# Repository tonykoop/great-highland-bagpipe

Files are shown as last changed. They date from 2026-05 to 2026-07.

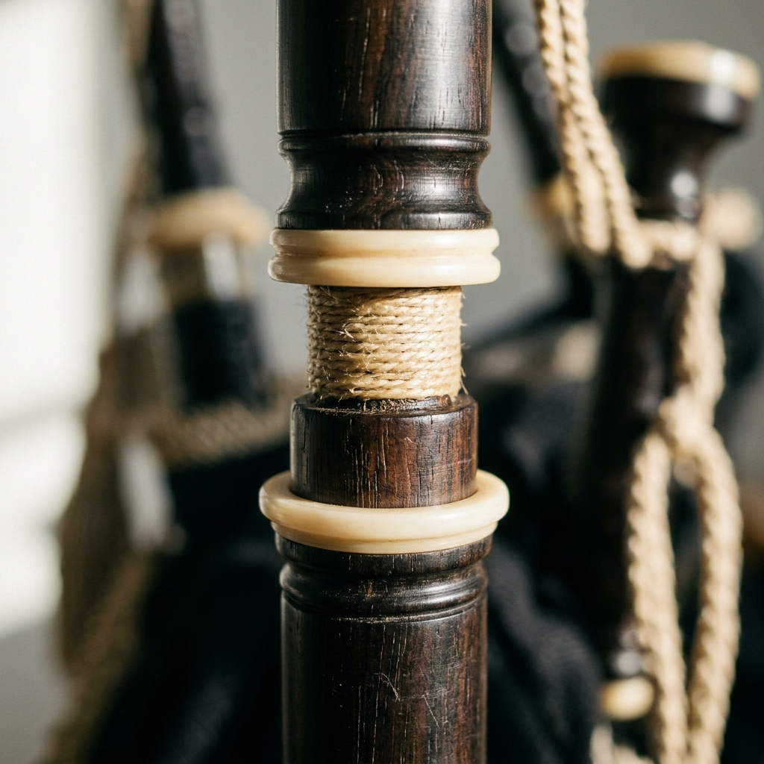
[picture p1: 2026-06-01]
images/macro/hemped-tuning-slide.png

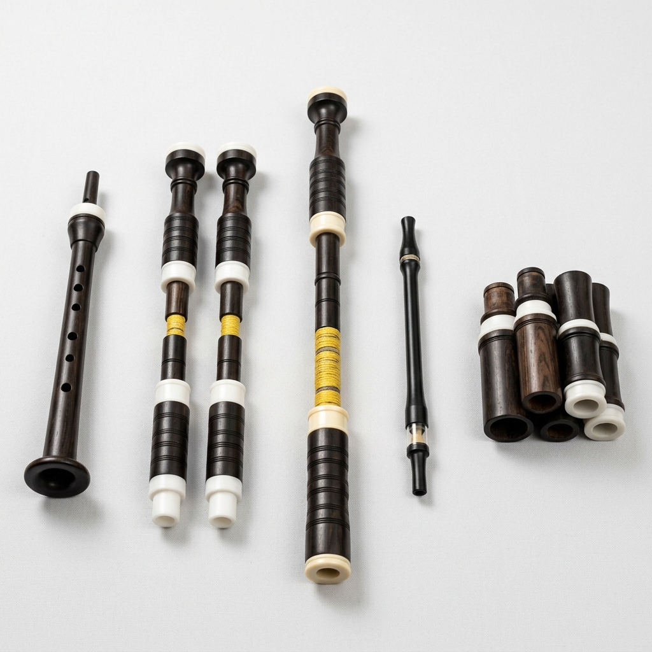
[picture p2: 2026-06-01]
images/family-group.png

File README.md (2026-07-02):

# Great Highland Bagpipe

> A system-of-systems engineering packet for a full Great Highland Bagpipe set:
> chanter, drones, reeds, bag, stocks, blowpipe, pressure regulation, tuning,
> sourcing, maintenance, and validation.

Great Highland Bagpipe system map

## GitHub Repo Metadata

**Description:** Parametric Great Highland Bagpipe build packet covering the
chanter, tenor and bass drones, reeds, bag pressure, stocks, blowpipe, tuning,
maintenance, sourcing, and validation.

**Suggested topics:** `great-highland-bagpipe`, `bagpipe`, `woodwind`,
`reed-instrument`, `parametric-design`, `acoustic-modeling`, `cnc-lathe`,
`woodturning`, `wolfram`, `instrument-making`, `build-packet`

## What This Is

This repository turns the Great Highland Bagpipe workbook into an L2/L3-candidate
packet. It treats the instrument as an interacting set of subsystems rather
than a single pipe: the conical double-reed chanter, two tenor drones, one bass
drone, three drone reeds, one chanter reed, five stocks, blowpipe valve,
reservoir bag, hemped tuning slides, and a maintenance/validation loop.

The design starts from `great-highland-bagpipe-design-table.xlsx`, which uses a
modern GHB Low A of 480 Hz, just-intonation chanter ratios, and first-pass
dimensions for a full chanter and drone set. Formula-derived dimensions are
marked as first-order estimates until confirmed against a physical reed, bore,
and pressure setup.

## Packet Map

- [`design.md`](design.md) - governing acoustic model, subsystem interfaces,
  pressure model, assumptions, and hardware alignment.
- [`bom.csv`](bom.csv) - bill of materials with part categories, operations,
  drawing references, and substitute rules.
- [`sourcing.csv`](sourcing.csv) - supplier/search tracker with current-check
  fields left for purchasing.
- [`cut-list.csv`](cut-list.csv) - rough and finished stock sizes for chanter,
  drones, stocks, blowpipe, mounts, and fixtures.
- [`validation.csv`](validation.csv) - tuning, pressure, leakage, fit, and
  maintenance checks.
- [`reed-pressure-validation.csv`](reed-pressure-validation.csv) - reed source
  roles, onset/cutoff pressure gates, and coupled pressure-response evidence
  rows kept at measurement-required status until real manometer/tuner data
  exists.
- [`assembly-manual.md`](assembly-manual.md) - shop sequence from reeds-first
  testing through final maintenance.
- [`risks.md`](risks.md) - acoustic, structural, ergonomic, supply, and
  fit/finish risk tests.
- [`drawings/`](drawings/) - first-pass dimensioned SVG sheets.
- [`cad/`](cad/) - parametric OpenSCAD master starter.
- [`wolfram/`](wolfram/) - generated Wolfram source package (chanter/drone
  stopped-pipe model); source-only, not executed.
- [`evolution/`](evolution/) - evolution-pipeline Stage 0 intake: master
  manifest, design-intent, and revision register (Gate A not yet run).
- [`site/`](site/) - static build-log site generated from the packet.

## System Architecture

| Subsystem | Function | First Prototype Decision |
| --- | --- | --- |
| Chanter | Conical double-reed melody pipe | Use the workbook's 14.5 in full-chanter length and tune holes from undersize with a commercial reed. |
| Tenor drones | Two stopped cylindrical A3 reference pipes | Build both identically; validate one tenor before copying the second. |
| Bass drone | Stopped cylindrical A2 reference pipe | Build in bottom/middle/top sections with long tuning overlap. |
| Reeds | Oscillating valves and pitch drivers | Buy commercial chanter and drone reeds for prototype stability. |
| Bag | Pressure reservoir | Buy synthetic zipper bag for repeatable airtightness. |
| Stocks and blowpipe | Airtight mechanical interfaces | Turn as separate service parts with hemped or tied-in seals. |
| Maintenance | Keeps the system stable | Add leakage, hemp, moisture, and reed checks to every validation pass. |

## Build Order

1. Buy reeds and bag first, because the acoustic system cannot be validated
   without real pressure and real reed behavior.
2. Turn a practice/prototype chanter in cherry, walnut, Delrin, or ipe before
   committing African blackwood.
3. Validate the chanter bore and note holes using tape and incremental
   enlargement.
4. Build one tenor drone, tune its reed seat and slide behavior, then duplicate
   it.
5. Build the bass drone after tenor tuning and leakage are stable.
6. Turn stocks and blowpipe, tie into the bag, and run full pressure tests.

## Status

**Status:** L2 V5 build-packet candidate

All required V5 baseline files present. All validation gates remain
`Pending` — instrument is not build-ready until reed, bore, and pressure
measurements are completed.

| Area | Status |
| --- | --- |
| V5 readiness | L2 candidate — visual-output-register.csv and cad/mcp-session-log.md present |
| Workbook | Existing `great-highland-bagpipe-design-table.xlsx` inspected and promoted into packet files |
| Acoustic model | First-order conical chanter plus stopped cylindrical drones documented |
| Manufacturing plan | Lathe/CNC workflow and cut list drafted |
| Sourcing | Prototype and final-material sourcing tracker drafted |
| Validation | Tuning, pressure, leakage, fit, maintenance, reed onset/cutoff, and pressure-response checks drafted; all Pending |
| Drawings | First-pass subsystem SVG drawings included (concept_only / derived_preview) |
| CAD | OpenSCAD master starter present; pending_measurement authority |
| Site/deck/print packet | Generated artifacts live at repo root and `site/` |

## License

[CC BY 4.0](LICENSE) - see LICENSE for details.

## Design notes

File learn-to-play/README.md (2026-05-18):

# learn-to-play / Great Highland Bagpipe

Starter songbook for the Great Highland Bagpipe build packet. Generated by the sheet-music skill.

The bagpipe chanter uses a narrow nine-note scale over a constant drone. These arrangements keep the beginner focus on steady pressure, scale familiarity, and clean doublings.

Range: **Low G - High A on the Highland chanter. Written in pipe notation around A mixolydian.**

## Folder map
| Folder | Contents |
|---|---|
| `00-warmup-scales/` | Pipe-scale range walk, birl/doubling drill, drone-pressure long tones |
| `01-easy/` | Three public-domain airs and hymns arranged inside the pipe scale |
| `02-intermediate/` | Two march-style studies with grace-note placeholders |
| `03-original/` | *Heather Drone March* - Heifer Zephyr original |
| `fingering-charts.svg` | Highland chanter fingering chart, Low G to High A |

## Repertoire

### 01-easy
| Tune | Tradition |
|---|---|
| Auld Lang Syne | Scots traditional / Robert Burns (1788) |
| Amazing Grace | John Newton / New Britain tune, public domain |
| Highland Laddie | Trad Scots tune (pre-1800) |

### 02-intermediate
| Tune | Tradition |
|---|---|
| Skye Boat Air | Harold Boulton / Annie MacLeod melody (1884) |
| Pipe Scale March | Original chanter study |

### 03-original
**Heather Drone March** - 32-bar 2/4 march-style original, A mixolydian, quarter=92.

## Notes on notation
ABC files are learner sketches, not full pipe-band settings. Grace-note groups are marked plainly and should be replaced by house-style embellishments during instruction.

## L2 readiness and known gaps
This starter songbook is ready for L2 review as a playable packet draft: ABC melodies, per-tune notes, static fingering summaries, warmups, and a top-level chart are present. Known gaps: generated audio, MusicXML, LilyPond, MIDI, and printable songsheets are skipped until the shared render dependencies are available; fingering charts need builder review against the final hole layout.

## License
Arrangements MIT-licensed by Tony Koop / Heifer Zephyr. Public-domain tune provenance is listed in each `notes.md`. Original studies are MIT-licensed for performance, recording, arrangement, and adaptation.

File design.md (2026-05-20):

# Great Highland Bagpipe Build Packet

## Intent

Build a first-pass engineering packet for a complete Great Highland Bagpipe set
that exposes the system interactions: chanter bore and reed, drones and drone
reeds, bag pressure, stocks, blowpipe valve, tuning slides, sourcing,
maintenance, and validation. The goal is not to claim a finished concert-grade
set from formulas alone; it is to define the measured build loop that gets from
workbook geometry to a playable, serviceable prototype.

## Catalog Metadata

| Field | Value |
| --- | --- |
| Instrument ID | GHB-001 |
| Slug | great-highland-bagpipe |
| Family | reed |
| Pipeline | cnc-lathe |
| Reference workbook | `great-highland-bagpipe-design-table.xlsx` |
| Done-bar family | reed woodwinds, closest local sisters: `chalumeau`, `duduk` |
| Date | 2026-05-08 |

## Design Inputs

| Parameter | Workbook value | Notes |
| --- | ---: | --- |
| Chanter Low A | 480 Hz | Modern GHB pitch, not A440 concert pitch |
| Speed of sound | 13510 in/s | Workbook value, roughly room-temperature air |
| Chanter scale | Mixolydian-like, just intonation | Tuned to drones, not equal temperament |
| Wood reference | African blackwood | Ipe, cocobolo, Delrin, maple, cherry, walnut are prototype alternatives |
| Drone tuning | two A3 tenors, one A2 bass | Tenors one octave below Low A; bass two octaves below |
| Bag pressure | 18-25 inH2O first-pass range | Pressure changes reed pitch and stability |

## Governing Model

The Great Highland Bagpipe is a coupled reed/resonator/reservoir system. The
packet intentionally uses different first-order models for different
subsystems, then validates the coupled result under pressure.

### Chanter

The chanter is a conical bore driven by a double reed. A conical reed pipe
behaves closer to an open-open pipe for pitch than a cylindrical stopped pipe,
but tone holes, reed compliance, and bore taper dominate the final intonation.
The workbook dimensions and measured practice-chanter hole positions are the
starting geometry.

```text
f_chanter ~= c / (2 * L_eff)
L_eff ~= c / (2 * f_target)
c = speed of sound in inches per second
```

Worked example from the workbook:

```text
Low A = 480 Hz
c = 13510 in/s
L_eff = 13510 / (2 * 480) = 14.073 in
Workbook physical full chanter length = 14.5 in
```

The difference between effective and physical length is expected because the
reed seat, conical end behavior, bell flare, and tone-hole network all shift the
effective acoustic length. Final tuning must start with undersize holes and
open them by measurement.

### Drones

The drones are cylindrical single-reed pipes, closed at the reed end and open at
the top. They are first-pass stopped pipes with odd-harmonic emphasis.

```text
f_drone ~= c / (4 * L_eff)
L_eff ~= c / (4 * f_target)
```

Worked examples from the workbook:

```text
Tenor drone A3 = 240 Hz
L_eff = 13510 / (4 * 240) = 14.073 in

Bass drone A2 = 120 Hz
L_eff = 13510 / (4 * 120) = 28.146 in
```

The workbook's physical sections intentionally exceed or subdivide these
effective lengths because tuning chambers, hemped slides, reed seats, and cap
geometry move the acoustic endpoint.

### Bag Pressure And Reeds

The bag is a pressure reservoir, not just a container. The reed only oscillates
inside a stable pressure window. Pressure changes can sharpen or destabilize
the chanter and drones, so every tuning row in `validation.csv` includes
environment and pressure notes.

```text
cents_error = 1200 * log2(measured_hz / target_hz)
pressure_target = 18-25 inH2O for first prototype testing
```

`family-spec.csv` now records the source role for each reed-coupled subsystem.
The chanter is treated as an empirically seeded conical reed pipe for planning
purposes, with final authority coming from purchased double-reed measurements.
The drones are treated as empirically seeded stopped reed pipes, with the
second tenor explicitly blocked from copy status until the first tenor reed,
slide, and pressure response are measured. `reed-pressure-validation.csv`
defines the pressure gates that must be filled before any reed, bore, slide, or
coupled tuning claim can move beyond `measurement_required`.

Do not use the 18-25 inH2O range as measured evidence by itself. It is only the
planned normal-play test window until a manometer log records onset pressure,
normal-play stability, cutoff/choke behavior, reed setting, and cents error for
the selected chanter and drone reeds.

### Empirical Correction Guard

No Native American flute K2 correction is applied here. This packet uses
first-order conical/stopped-pipe estimates plus measured GHB-specific
validation rows. Any future correction must be derived from measured chanter,
drone, reed, and pressure data from this family.

## Chanter Scale Table

| Note | Ratio to Low A | Target Hz at Low A 480 | Model L_eff in | Prototype action |
| --- | ---: | ---: | ---: | --- |
| Low G | 8/9 | 426.67 | 15.832 | Validate as cross/fingering-dependent low note |
| Low A | 1/1 | 480.00 | 14.073 | Establish reed strength and pressure first |
| B | 9/8 | 540.00 | 12.509 | Drill undersize, tape-tune up |
| C written C# | 5/4 | 600.00 | 11.258 | Drill undersize, tune against drones |
| D | 4/3 | 640.00 | 10.555 | Check just fourth against drones |
| E | 3/2 | 720.00 | 9.382 | Watch high hand spacing and hole size |
| F written F# | 5/3 | 800.00 | 8.444 | Small tuning changes are sensitive |
| High G | 7/4 | 840.00 | 8.042 | Treat as cross-fingering/harmonic validation |
| High A | 2/1 | 960.00 | 7.036 | Validate as octave behavior, not a simple hole row |

## Subsystem Interfaces

| Interface | Critical fit | Validation |
| --- | --- | --- |
| Chanter reed to chanter seat | Airtight staple fit, stable blade opening | Reed seats without wobble; Low A speaks at target pressure |
| Chanter stock to bag | Stock tie-in and hemp seal | No bubbles in leak test |
| Drone reed to drone seat | Reed body matches seat diameter | Reed starts, cuts off, and restarts predictably |
| Drone slides | Hemped tenon/socket with tuning travel | Smooth movement, no air loss, no sudden pitch jumps |
| Blowpipe valve | One-way seal | Bag holds pressure when player stops blowing |
| Bag to stocks | Mechanical tie-in | 60-second pressure hold test |

## Hardware Alignment

| Operation | Tooling | Fixture | Notes |
| --- | --- | --- | --- |
| Chanter exterior turning | Lathe roughing/detail tools | Between centers, then chuck/collet | Leave extra length for holding and trimming |
| Chanter conical bore | Step drills plus custom tapered reamer | Headstock-driven deep bore setup | Bore straightness is a high-risk acoustic variable |
| Tone holes | Drill press or mill, undersize bits | V-block indexed to front/back datum | Open by reaming/sanding while measuring pitch |
| Drone cylindrical bores | Long brad-point/twist drills, reamers | Lathe center drilling and steady rest | Build one tenor as process proof |
| Tuning slides | Lathe turning and parting tools | Matched tenon/socket gauges | Hemp clearance must be planned, not guessed |
| Stocks | Lathe boring tools | Batch fixture for repeated stock bodies | Tie-in groove must not cut too deep |
| Mounts/ferrules | Lathe, optional laser engraving | Mandrels for Delrin/ferrule rings | Keep decorative parts removable in prototype |

## Build Strategy

Prototype order is deliberately reeds-first and pressure-first:

1. Buy three chanter reeds and one synthetic drone reed set.
2. Buy a synthetic zipper bag and blowpipe valve before final tuning work.
3. Build a practice/prototype chanter in cherry, walnut, ipe, or Delrin.
4. Validate bore, reed, and hole tuning before building African blackwood.
5. Build one tenor drone, then duplicate it after measured success.
6. Build the bass drone after slide and reed behavior are stable.
7. Tie in stocks, run leakage tests, and maintain a tuning/pressure log.

## Assumptions And Unknowns

| Item | Status | Why it matters |
| --- | --- | --- |
| Chanter bore station table | Derived from workbook and practice measurements | Final intonation needs measured stations, not only a linear cone |
| Reed brand/strength | Unknown until purchased | Reed compliance changes pitch, pressure, and response |
| Bag actual volume | Supplier-dependent | Affects stability and ergonomic squeeze behavior |
| Drone reed seat dimensions | Must match chosen reeds | Synthetic reed body diameters vary |
| Final decorative mount dimensions | Flexible | Do not let ornament drive acoustic or service dimensions |

## Validation Plan

Validation starts with the subsystem, then moves to the coupled system:

1. Bench leak test every stock, reed seat, slide, and bag tie-in.
2. Measure pressure at start, normal play, and cut-off for chanter and drones.
3. Tune drones without the chanter, then add chanter and listen for beating.
4. Record note frequency, cents error, pressure, temperature, humidity, reed,
   and corrective action in `validation.csv`.
5. Repeat after 24 hours to catch hemp compression, bag leakage, and moisture
   effects.

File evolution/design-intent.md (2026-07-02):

# Design Intent — great-highland-bagpipe rev A

- Master CAD: `cad/great-highland-bagpipe-master.scad` (sha256: 7bcdc95fce3c7fae077277482be11eb72df51515757a26632cf0f1e08deeaa63), driven by `great-highland-bagpipe-design-table.xlsx` (sha256: 3ddafd30d57a32bd5da541066588c79f2f1255a5bc5907dc597e76836bcbe0d7)
- Function: Full Great Highland Bagpipe system — conical-bore chanter (open-open, cane double reed) coupled to two tenor + one bass stopped-pipe drones (synthetic/cane reeds), fed by a pressurized bag (18-25 inH2O first-pass range) through a blowpipe one-way valve and turned stocks. Chanter plays a just-intonation Mixolydian-like scale tuned to the drones, not equal temperament (design.md).
- Environment: hand-blown, sustained-pressure system; reed response and drone onset/cutoff are pressure-dependent; wood body (African blackwood preferred, Delrin/ipe/cherry for prototyping) is a coupled reed/resonator/reservoir system, not a simple first-order pipe.
- Target qty: 1 (prototype set — 1 chanter, 2 tenor drones, 1 bass drone). Deadline: TBD. Budget/unit ceiling: TBD.

## Critical dimensions (carry tolerances)

| Feature | Nominal | Tolerance | Why critical | Source |
| --- | --- | --- | --- | --- |
| Chanter Low A | 480 Hz | onset/normal-play/cutoff pressure logged (validation.csv) | pitch reference, not concert A440 | family-spec.csv GHB-CHANTER (measurement_required) |
| Chanter predicted length | 14.5 in | cents error vs validation.csv after reed fit | intonation | family-spec.csv GHB-CHANTER (empirically_seeded) |
| Chanter bore | 0.157-0.800 in conical | undersize holes first, enlarge incrementally (risks.md) | acoustic/reed agreement | family-spec.csv GHB-CHANTER (empirically_seeded) |
| Tenor drone (A3) length | 17.0 in | unison match to reference tenor before duplicating | drone tuning | family-spec.csv GHB-TENOR-1 (empirically_seeded) |
| Bass drone (A2) length | 32.0 in | onset/cutoff/drift measured after tenor stability | drone tuning | family-spec.csv GHB-BASS (empirically_seeded) |
| Bag pressure | 18-25 inH2O | manometer readings during 10-min play simulation | reed pitch/stability | design.md Design Inputs (measurement_required) |
| Blowpipe bore | 0.500 in | must hold pressure, no reverse flow, before reed tests | pressure supply reliability | family-spec.csv GHB-BLOWPIPE (measurement_required) |

## Incidental (free for DFM)

- Decorative turning/mounts, hemp/beeswax wrap cosmetics, bag cover fabric choice, non-mating stock ornamentation.

## Must-nots (DFM may never violate)

- Do not lock final bore/hole geometry from the first-order `c/(2L)`/`c/(4L)` estimate alone — chanter bore, reed, tone-hole network, and bag pressure are a coupled system (risks.md "Acoustic Chanter Bore And Reed Do Not Agree").
- Do not bore/ream final blackwood before proving the workflow in Delrin/ipe/cherry — long small-diameter bores in blackwood risk heat-checking and wander (risks.md structural risk).
- Do not duplicate the second tenor drone until the first tenor's reed seat and slide behavior are measured and validated (family-spec.csv GHB-TENOR-2).
- Do not treat any bore/length/pressure value as build-ready until validation.csv gates clear — all currently `measurement_required` or `empirically_seeded`.

## Material intent

- Preferred: African blackwood (final), per bom.csv.
- Acceptable subs: Delrin, ipe, cherry, walnut, maple for prototyping (bom.csv notes: use for first prototype, avoid final blackwood until bore workflow is proven).
- Forbidden: none recorded beyond the prototype-before-blackwood sequencing above.

## Stage status

Stage 0 intake complete 2026-07-01. Gate A (Alpha shop compile) NOT yet run — no concessions logged, nothing presented as shippable.

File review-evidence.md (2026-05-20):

# Review Evidence

Refs #1.

## Round 3 Scope

- Re-validated the existing root-mode packet as part of the wind build-packet
  sweep.
- Existing packet already includes Great Highland Bagpipe specifics: chanter
  scale centered around modern A, stopped-pipe drone model, drone tuning,
  reed selection, pressure/leak validation, and subsystem build order.
- This packet remains an L2/L3-candidate system packet, not a measured build.

## Gates Before Close

- Buy or select real chanter and drone reeds before finalizing bores.
- Record bag pressure, leakage, drone lock, chanter scale, reed response, and
  maintenance checks in `validation.csv`.
- Confirm public-facing language and sourcing before release.

## Round 33C/D Reed And Pressure Slice

- Added `reed-pressure-validation.csv` as a focused measurement ledger for
  chanter/drone reed source roles, onset pressure, normal-play pressure
  response, cutoff/choke behavior, full-set coupling, and pressure-system
  control checks.
- Added acoustic-law, end-condition, dimension-provenance, reed-source-role,
  pressure-dependency, and pressure-validation-status columns to
  `family-spec.csv`.
- Preserved authority boundaries: pressure and reed behavior remain
  `measurement_required` until repo-local manometer, tuner, reed-setting, and
  leak-test evidence exists.

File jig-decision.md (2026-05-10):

# Jig Decision

| Operation | Jig choice | Reason | Release check |
| --- | --- | --- | --- |
| Chanter turning | Lathe between centers with bore reference | Chanter taper and hole layout need a stable centerline | Bore profile and OD stations are measured before drilling |
| Drone sections | Lathe mandrel and stop collars | Tenor drones must duplicate cleanly | First tenor validates before second is copied |
| Reed-seat work | Hand ream with commercial reed in hand | Reed fit dominates pitch stability | Reed seats without rocking and starts consistently |
| Stock/blowpipe fit | Taper gauges and leak test plugs | Airtight interfaces are mandatory | Bag pressure leak test passes before tuning |
| Hole drilling | Indexed drilling fixture | Chanter holes require angular and station control | Undersize holes match drawing before tuning enlargement |

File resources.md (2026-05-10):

# Resources

## System Context

The Great Highland Bagpipe packet is a system packet: chanter, drones, reeds,
bag, stocks, blowpipe, pressure regulation, and maintenance all interact. Public
claims should distinguish formula-derived dimensions from reed-and-pressure
validated dimensions.

## Sources To Confirm Before L3

- Modern pitch target and chanter scale reference used for the build.
- Commercial reed dimensions and pressure behavior.
- Drone reed seat and tuning-slide dimensions from measured examples.
- Bag, stock, and blowpipe interface dimensions from chosen hardware.
- Maintenance references for hemping, moisture control, and leakage checks.

## Related Repos

- `tonykoop/instrument-maker` for conical bore, stopped-pipe, and validation
  gates.
- `tonykoop/flutes` for tuner-log discipline. NAF K2 corrections do not apply
  to reed-driven bagpipe bores.

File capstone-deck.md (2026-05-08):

# Great Highland Bagpipe Capstone
- Musical instrument documentation capstone
- Build packet: great-highland-bagpipe
- Generated: 2026-05-08

---

# Project Intent
- Build a first-pass engineering packet for a complete Great Highland Bagpipe set
that exposes the system interactions: chanter bore and reed, drones and drone
reeds, bag pressure, stocks, blowpipe valve, tuning slides, sourcing,
maintenance, and validation. The goal is not to claim a finished concert-grade
set from formulas alone; it is to define the measured build loop that gets from
workbook geometry to a playable, serviceable prototype.

_Speaker notes:_ Read design.md before committing to dimensions or sourcing decisions.

---

# Physics Model
- The Great Highland Bagpipe is a coupled reed/resonator/reservoir system. The
packet intentionally uses different first-order models for different
subsystems, then validates the coupled result under pressure.

```
f_chanter ~= c / (2 * L_eff)
L_eff ~= c / (2 * f_target)
c = speed of sound in inches per second
```

```
Low A = 480 Hz
c = 13510 in/s
L_eff = 13510 / (2 * 480) = 14.073 in
Workbook physical full chanter length = 14.5 in
```

```
f_drone ~= c / (4 * L_eff)
L_eff ~= c / (4 * f_target)
```

```
Tenor drone A3 = 240 Hz
L_eff = 13510 / (4 * 240) = 14.073 in

Bass drone A2 = 120 Hz
L_eff = 13510 / (4 * 120) = 28.146 in
```

```
cents_error = 1200 * log2(measured_hz / target_hz)
pressure_target = 18-25 inH2O for first prototype testing
```

_Speaker notes:_ Governing equations extracted verbatim from design.md. Apply empirical corrections (NAF K2, scale offsets) only where the model permits — see references/acoustic-models.md.

---

# Hardware Alignment

| Operation | Tooling | Fixture | Notes |
| --- | --- | --- | --- |
| Chanter exterior turning | Lathe roughing/detail tools | Between centers, then chuck/collet | Leave extra length for holding and trimming |
| Chanter conical bore | Step drills plus custom tapered reamer | Headstock-driven deep bore setup | Bore straightness is a high-risk acoustic variable |
| Tone holes | Drill press or mill, undersize bits | V-block indexed to front/back datum | Open by reaming/sanding while measuring pitch |
| Drone cylindrical bores | Long brad-point/twist drills, reamers | Lathe center drilling and steady rest | Build one tenor as process proof |
| Tuning slides | Lathe turning and parting tools | Matched tenon/socket gauges | Hemp clearance must be planned, not guessed |
| Stocks | Lathe boring tools | Batch fixture for repeated stock bodies | Tie-in groove must not cut too deep |
| Mounts/ferrules | Lathe, optional laser engraving | Mandrels for Delrin/ferrule rings | Keep decorative parts removable in prototype |

_Speaker notes:_ Identifies which shop pipeline(s) this instrument lives in: Bambu+kiln slip-cast, 40W laser flat-pack, CNC+lathe, segmented turning, drum-skin work, or hybrid combinations.

---

# How To Use This Packet
- Start with design.md for intent and assumptions.
- Use bom.csv, sourcing.csv, and cut-list.csv before buying or cutting.
- Use drawing-brief.md and CAD/CNC folders before machining.
- Print the packet for shopping, shop work, and validation.

---

# File Map
- design.md: Project intent, catalog metadata, assumptions, and validation plan.
- bom.csv: Starter bill of materials with part categories, quantities, drawing refs, and notes.
- sourcing.csv: Supplier/search tracker with specs, price/date fields, lead time, substitutes, and risks.
- cut-list.csv: Rough/final stock sizes, material, grain/orientation, operations, yield, and offcuts.
- drawing-brief.md: Manufacturing drawing and technical product sketch brief.
- assembly-manual.md: Shop-facing sequence, tools, fixtures, safety, tuning, finishing, and maintenance notes.
- validation.csv: Target/measured values, tolerance, environment, result, and tuning/build action log.
- supplier-rfq.md: Supplier email/request-for-quote starter.

---

# Family Spec

| member_id | subsystem | target_note | target_hz | predicted_length_in | bore_in | role | prototype_priority |
| --- | --- | --- | --- | --- | --- | --- | --- |
| GHB-CHANTER | chanter | Low A | 480 | 14.5 | 0.157-0.800 conical | melody pipe | 1 |
| GHB-TENOR-1 | drone | A3 | 240 | 17.0 | 0.344/0.563 stepped | tenor drone reference | 2 |
| GHB-TENOR-2 | drone | A3 | 240 | 17.0 | 0.344/0.563 stepped | second tenor unison | 3 |
| GHB-BASS | drone | A2 | 120 | 32.0 | 0.375/0.438/0.625 stepped | bass drone reference | 4 |
| GHB-BLOWPIPE | pressure | pressure supply |  | 12.0 | 0.500 | air inlet and valve | 5 |
| GHB-STOCKS | interface | airtight fit |  | 3.0 | 0.813 nominal | bag interface set | 6 |

_Speaker notes:_ Sizes scale via the master scale factor; tuning targets are first-order Helmholtz/cantilever predictions to be empirically corrected per prototype.

---

# Build Workflow
- Design and assumptions
- Source materials and hardware
- Prepare stock, fixtures, and CNC/laser/lathe setup
- Assemble, tune, finish, and validate

---

# Sourcing And BOM
- BOM gives part categories and drawing references.
- Sourcing tracks search terms, supplier candidates, price/date, lead time, substitutions.
- Visual BOM brief turns the parts list into a presentation-ready image board.

---

# Shop Packet
- Cut list for lumber/sheet/blank planning.
- Assembly manual for away-from-keyboard work.
- Validation sheet for measured dimensions, tuning, pass/fail checks.

---

# Drawings, CAD, CNC
- drawing-brief.md defines required views, dimensions, datums, sketch intent.
- cad/ holds models and design tables.
- cnc/ holds CAM, toolpaths, setup sheets, dry-run notes.
- drawings/ holds PDFs, SVGs, DXFs, drawing exports.






---

# Images And Screenshots
- images/ghb-system-map.svg



---

# Validation Plan
- A4 = 440 Hz reference check.
- Tuning targets logged in validation.csv.
- Critical dimensions verified against design sheet and CAD.
- Photos and revision notes after each major step.

---

# Open Risks / Decisions
- TBDs in design sheet and BOM.
- Supplier price/availability not yet verified.
- Generated images marked as concept placeholders.
- Empirical corrections await measured prototype data.

---

# Next Actions
- Replace TBDs with measured/source-backed values.
- Verify live supplier price and availability before buying.
- Export final drawings and visual BOM images.
- Regenerate this deck and print packet after final edits.

---

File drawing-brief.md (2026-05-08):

# Drawing Brief

## Drawing Set

| Drawing | Purpose | Required datums |
| --- | --- | --- |
| `drawings/ghb-chanter-front.svg` | Chanter body, tone-hole datum chain, bore section | Datum A = sole/bell end, Datum B = reed seat axis, Datum C = front hole line |
| `drawings/ghb-drone-set.svg` | Tenor and bass section lengths, bores, tuning-slide interfaces | Datum A = reed seat end, Datum B = slide shoulder, Datum C = sound exit |
| `drawings/ghb-pressure-interface.svg` | Bag, stocks, blowpipe, valve, pressure path | Datum A = bag centerline, Datum B = stock tie-in groove |
| `drawings/ghb-system-validation.svg` | Validation flow: pressure, leak, drone tuning, chanter tuning, maintenance retest | Datum A = subsystem test order |

## Standards

- Units: inches with metric equivalents added later where useful.
- Default tolerance: +/-0.005 in for turned acoustic features; +/-0.015 in for
  decorative exterior features; fit-specific tolerances must be measured from
  purchased reeds and bag hardware.
- Critical dimensions must trace to `great-highland-bagpipe-design-table.xlsx`
  or measured supplier parts.
- Any reed-seat or stock dimension not measured yet is marked "measure chosen
  part" rather than guessed.

## Chanter Notes

The tone-hole coordinates in the workbook include measured practice-chanter
locations and first-pass target full-chanter values. The drawing must show
undersize drill diameters and leave final tuning by measurement.

## Drone Notes

Drone drawings must show effective acoustic length separately from physical
section length. Tuning slides, reed seats, and cap geometry move the acoustic
endpoint.

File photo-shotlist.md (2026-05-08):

# Photo Shotlist

## Before Cutting

- Purchased chanter reeds with calipers on staple OD and blade width.
- Synthetic drone reed set with reed body diameters measured.
- Synthetic bag laid flat with stock-hole layout visible.
- Wood or Delrin blanks next to ruler and moisture/label info.

## During Build

- Chanter blank between centers before drilling.
- Bore drilling setup with tailstock and support.
- Tapered reamer entering the chanter bore.
- Tone-hole drilling fixture and front/back datum marks.
- Hemped drone slide before and after waxing.
- Stock tie-in before cover installation.

## Validation

- Manometer connected during pressure test.
- Tuner reading for Low A with pressure noted.
- Drone tuning slide position for tenor A3 and bass A2.
- Leak-test bubbles or pressure decay setup.
- 24-hour retest setup.

## Finished

- Full set assembled on bag.
- Chanter detail with reed.
- Drone tops and mounts.
- Maintenance kit: reeds, hemp, beeswax, tuner, manometer.

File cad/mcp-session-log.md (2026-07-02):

# MCP Session Log

V5 provenance — aligned with `tonykoop/instrument-maker` V5 build-packet standard.

No Claude Desktop MCP session was run for this packet. The OpenSCAD master
starter was hand-authored from the committed design-table and workbook references.
No fabrication authority has been claimed for any output.

| session_id | tool | input_authority | outputs | role | authority_result | review_status | notes |
| --- | --- | --- | --- | --- | --- | --- | --- |
| 2026-05-29-ghb-master-scad-v1 | openscad | great-highland-bagpipe-design-table.xlsx; family-spec.csv | cad/great-highland-bagpipe-master.scad | cad_authoring | pending_measurement | unreviewed | Master starter scaffold; chanter and drone geometry from design-table seed values; NOT fabrication authority. All bore and hole positions require physical reed and bore measurement before any CAD/DXF authority is claimed. |
| 2026-05-29-svg-drawings-v1 | illustrator_manual | great-highland-bagpipe-design-table.xlsx | drawings/ghb-chanter-front.svg; drawings/ghb-drone-set.svg; drawings/ghb-pressure-interface.svg; drawings/ghb-system-validation.svg | drawing_cleanup | derived_preview | unreviewed | First-pass SVG layout drawings; review previews only; not CNC toolpath or inspection authority. |
| fable-v5-refresh-2026-07-01 | claude-code (Fable 5) | great-highland-bagpipe-design-table.xlsx, bom.csv, sourcing.csv, cut-list.csv, validation.csv | bom.csv, sourcing.csv, cut-list.csv, validation.csv | packet_refresh | fabrication | self_checked | V5 refresh pass: README status line format fixed (bold-colon bug); tabular packet data reviewed against design-table baseline, no dimension changes made. |
| fable-v5-refresh-2026-07-01 | claude-code (Fable 5) + OpenSCAD CLI | great-highland-bagpipe-design-table.xlsx | cad/great-highland-bagpipe-master.scad | cad_authoring | pending_measurement | self_checked | Existing master kept as-is (no rewrite). openscad render check: pass (openscad -o STL, exit 0). |
| fable-v5-refresh-2026-07-01 | claude-code (Fable 5) + generate_wolfram_packet.py | great-highland-bagpipe-design-table.xlsx, family-spec.csv, validation.csv | wolfram/great-highland-bagpipe-wolfram-model.wl | analysis_source | derived_preview | unreviewed | Generated via $SKILL/generate_wolfram_packet.py (not executed — no --execute passed); renamed from instrument-model.wl; source-only L2 evidence. |

## Current Boundary

No MCP-connected CAD tool, image-generation tool, Wolfram runtime, or
external session has produced fabrication authority for this packet. All
CAD and drawing outputs carry `pending_measurement` or `derived_preview`
authority and must not be used as shop-floor fabrication geometry.

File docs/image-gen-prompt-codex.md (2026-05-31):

# Image Generation Prompt

Concept visualization only. Do not treat generated images as dimensional, tuning, CAD, DXF, or fabrication authority.

## Hero Prompt

Photorealistic studio product photograph of a complete Great Highland Bagpipe engineering prototype laid out as a system: conical chanter, two tenor drones, one bass drone, stocks, blowpipe with valve, synthetic zipper bag, hemped tuning slides, reeds arranged separately, and restrained mounts. Use dark hardwood or Delrin prototype parts with simple metal ferrules, clean neutral studio background, soft directional studio lighting, three-quarter product-photography angle, about a 50mm lens, high detail.

## In-Context Prompt

Photorealistic workshop validation scene of the bagpipe set partially assembled on a bench, bag inflated gently, drones supported, chanter nearby, manometer tubing and tuner visible, reed cases open. Natural window light, practical maintenance atmosphere, no parade costume, the image emphasizes pressure regulation, leakage checks, reed testing, and subsystem integration.

## Detail/Macro Prompt

Macro close-up of a hemped drone tuning slide and reed seat: turned dark wood, waxed hemp wrap, synthetic drone reed nearby, smooth ferrule, tiny moisture and maintenance details, shallow depth of field, photorealistic high detail.

## Negative / Avoid

Avoid tartan costume focus, logos, watermarks, readable text, fantasy pipes, incorrect number of drones, impossible bag connections, extra limbs, and unregulated compressed-air imagery.

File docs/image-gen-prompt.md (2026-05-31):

# Image-Gen Prompts

Concept image only; not fabrication authority. Do not include cut-ready dimensions, hole locations, or toolpaths.

## Hero Prompt

A complete Great Highland Bagpipe set rendered as a real, finished physical object: a soft tartan-covered reservoir bag at the center, with five turned wooden stocks tied into it and five pipes radiating from it in the classic recognizable silhouette — a short blowpipe with its valve end, a conical melody chanter dropping below the bag with a row of front tone holes and a flared sole, two identical tenor drones and one longer bass drone rising up and back over the player's shoulder line, the drones built in sections joined by hemped tuning slides and capped with sound-exit tops. Turned components in dark, fine-grained African blackwood with a satin oil finish, accented by pale ivory-look Delrin mounts, ferrules, and ring projections at the joints; the bag cover a muted wool tartan. Realistic scale cues: the bass drone reads roughly as long as a forearm, the chanter about the length of a hand-and-a-half. Clean neutral light-grey studio background, soft directional studio light, 3/4 product-photography angle, ~50mm lens, high detail, photorealistic, no text labels.

## In-Context Prompt

The same Great Highland Bagpipe set staged in a woodturner's workshop on a clean bench: the tartan bag resting with the three drones leaning up over a wooden cradle, the chanter laid in front beside a small maintenance kit of waxed hemp, a roll of natural hemp thread, a block of beeswax, and a couple of spare cane and synthetic reeds. A lathe and turning tools sit softly out of focus in the warm natural window light behind. Shallow depth of field holding the drone tops and chanter sharp, environmental storytelling of an in-progress hand build, concept visualization only.

## Detail Prompt

Macro close-up of a single drone tuning-slide joint: two turned blackwood sections meeting at a hemped tenon-and-socket, the wrapped natural hemp thread visible where the upper section telescopes into the lower, a pale Delrin ring projection and ferrule framing the joint, fine wood grain and the slight sheen of beeswax on the hemp. Raking light grazes across the turned beads and the hemp wrap to show texture and the telescoping tuning travel. High detail, photorealistic, no measurements.

## Negative / Avoid

No text, logos, watermarks, or fake maker marks; no dimension callouts or measurement lines; no impossible mechanisms, no extra or missing drones, no electronic parts; anatomically plausible hands if a player is shown.

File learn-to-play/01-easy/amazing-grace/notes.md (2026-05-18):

# Amazing Grace

**Tradition/source:** John Newton / New Britain tune, public domain
**Public domain:** Yes - pre-1929 US or original MIT
**Arrangement:** Starter L2 arrangement for `great-highland-bagpipe`.

## Range check
Low A-High A: within the beginner starter range for this packet.

## Practice tip
Tune drones first, then play slowly enough that every note locks to the drone.

## Known gaps
Audio, MusicXML, LilyPond, and printable songsheet stages are intentionally skipped until the shared render toolchain is installed. Fingering SVGs are static L2 review artifacts and should be checked against the final drilled hole layout before public release.

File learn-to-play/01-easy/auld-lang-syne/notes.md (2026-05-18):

# Auld Lang Syne

**Tradition/source:** Scots traditional / Robert Burns (1788)
**Public domain:** Yes - pre-1929 US or original MIT
**Arrangement:** Starter L2 arrangement for `great-highland-bagpipe`.

## Range check
Low G-High A: within the beginner starter range for this packet.

## Practice tip
Keep drones steady before adding embellishments; the melody is familiar enough to reveal pressure wobble.

## Known gaps
Audio, MusicXML, LilyPond, and printable songsheet stages are intentionally skipped until the shared render toolchain is installed. Fingering SVGs are static L2 review artifacts and should be checked against the final drilled hole layout before public release.

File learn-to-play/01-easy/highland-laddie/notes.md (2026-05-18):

# Highland Laddie

**Tradition/source:** Trad Scots tune (pre-1800)
**Public domain:** Yes - pre-1929 US or original MIT
**Arrangement:** Starter L2 arrangement for `great-highland-bagpipe`.

## Range check
Low G-High A: within the beginner starter range for this packet.

## Practice tip
March the pulse with the foot before increasing chanter speed.

## Known gaps
Audio, MusicXML, LilyPond, and printable songsheet stages are intentionally skipped until the shared render toolchain is installed. Fingering SVGs are static L2 review artifacts and should be checked against the final drilled hole layout before public release.

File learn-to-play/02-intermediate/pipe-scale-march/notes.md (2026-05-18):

# Pipe Scale March

**Tradition/source:** Original chanter study
**Public domain:** Yes - pre-1929 US or original MIT
**Arrangement:** Starter L2 arrangement for `great-highland-bagpipe`.

## Range check
Low G-High A: within the beginner starter range for this packet.

## Practice tip
Add doublings only after the plain melody is rhythmically square.

## Known gaps
Audio, MusicXML, LilyPond, and printable songsheet stages are intentionally skipped until the shared render toolchain is installed. Fingering SVGs are static L2 review artifacts and should be checked against the final drilled hole layout before public release.

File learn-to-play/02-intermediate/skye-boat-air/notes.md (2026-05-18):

# Skye Boat Air

**Tradition/source:** Harold Boulton / Annie MacLeod melody (1884)
**Public domain:** Yes - pre-1929 US or original MIT
**Arrangement:** Starter L2 arrangement for `great-highland-bagpipe`.

## Range check
Low G-High G: within the beginner starter range for this packet.

## Practice tip
Use as an air: steady bag, slower finger motion, and clear phrase endings.

## Known gaps
Audio, MusicXML, LilyPond, and printable songsheet stages are intentionally skipped until the shared render toolchain is installed. Fingering SVGs are static L2 review artifacts and should be checked against the final drilled hole layout before public release.

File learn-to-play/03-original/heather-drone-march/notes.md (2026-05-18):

# Heather Drone March

**Tradition/source:** Tony Koop / Heifer Zephyr (2026)
**Public domain:** Yes - pre-1929 US or original MIT
**Arrangement:** Starter L2 arrangement for `great-highland-bagpipe`.

## Range check
Low G-High A: within the beginner starter range for this packet.

## Practice tip
The drones are the metronome. Keep bag pressure even through every repeated A.

## Known gaps
Audio, MusicXML, LilyPond, and printable songsheet stages are intentionally skipped until the shared render toolchain is installed. Fingering SVGs are static L2 review artifacts and should be checked against the final drilled hole layout before public release.

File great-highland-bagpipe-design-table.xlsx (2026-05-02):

Great Highland Bagpipe — Full Set Design & Build Document
Chanter (conical bore, double reed) · 2 Tenor Drones + 1 Bass Drone (cylindrical bore, single reed) · Bag · Blowpipe · 5 Stocks
DESIGN INPUTS — Pitch & Tuning
Low A Pitch (Hz) | 480 | ← Standard modern pitch; adjust for A440 sets
Speed of Sound (in/s) | 13510
Scale Type | Mixolydian (flat 7th) | ← Low G, Low A, B, C#, D, E, F#, High G, High A
Tuning System | Just Intonation | ← Tuned to drones, NOT equal temperament
Wood | African Blackwood (Grenadilla) | ← Traditional; alt: Cocobolo, Polypenco (Delrin), 3D-print
Drone Tuning | 2× Tenor A3, 1× Bass A2 | ← Both tenors 1 octave below chanter Low A; bass 2 octaves
Bag Material | Synthetic (Gore-Tex/Bannatyne) | ← Alt: sheepskin, elk, Canmore hybrid
1. CHANTER — Conical Bore, Double Reed, Open Pipe (f = c / 2L)
Total Length (in) | 14.5 | Reed seat to sole; ~368 mm
Bore Throat (in) | 0.157 | 4mm; reed seat end
Bore Bell (in) | 0.800 | 20mm; open end
Taper Ratio |  | 22-33:1 typical
Wall Thickness (in) | 0.220
Outside Diam (in)
CHANTER SCALE (Mixolydian, Just Intonation)
Note | Ratio | Freq (Hz) | Eff Length (in) | Hole Diam (in) | Fingering (x=closed o=open)
Low G | 8:9 |  |  | 0.250 | xxx xxxx (all closed)
Low A (tonic) | 1:1 |  |  | 0.280 | xxx xooo
B | 9:8 |  |  | 0.240 | xxx oooo
C (written C#) | 5:4 |  |  | 0.280 | xxo oooo
D | 4:3 |  |  | 0.310 | xoo oooo
E | 3:2 |  |  | 0.280 | ooo xooo
F (written F#) | 5:3 |  |  | 0.220 | ooo oooo (all open)
High G (harmonic 7th) | 7:4 |  |  | 0.190 | ooo xooo (cross-finger)
High A (octave) | 2:1 |  |  |  | xxx xxxx + overblow (2nd register)
x=closed, o=open. Left hand: thumb+3 fingers. Right hand: 4 fingers.
CHANTER PHYSICAL DIMENSIONS (measure with calipers!)
Variable | Tony's Practice Chanter | Full Chanter (target) | Notes
BLANK & TURNING
Blank Length (in) | 15.750 | 16.5 | Allow 1" extra each end for chucking
Blank Cross-Section (in) | 1.0 x 1.0 (est) | 1.5 x 1.5 | Square stock; minimum for turning OD
OD at Reed Seat (in) | 0.500 | 0.880 | Tapers to fit stock socket
OD at Top Hole (in) | 0.870 | 1.000 | Thickest point of body
OD at Bell (in) | 0.750 | 1.250 | Flared sole/bell; widest point
BORE
Bore at Reed Seat (in) | 0.150 | 0.157 | 4mm typical; use long tapered reamer
Bore at Bell (in) | 0.565 | 0.800 | 20mm full; practice chanter is smaller
Taper Ratio |  |  | Note: Tony's chanter is mostly cylindrical (0.150") with a 2" bell flare — not a true taper!
FINGER HOLE COORDINATES — Tony's Measured Practice Chanter + Target Full Chanter
Hole | Measured (in from bell) | Target Full (in from sole) | Measured Diam (in) | Chamfer (in) | Hand / Note
7 (bottom, nearest bell) | 4.340 |  | 0.155 | 0.100 | RH pinky / High G
6 | 5.710 |  | 0.155 | 0.050 | RH ring / F#
5 | 6.875 |  | 0.155 | 0.050 | RH middle / E
4 | 7.625 |  | 0.128 | 0.050 | RH index / D
3 | 8.720 |  | 0.155 | 0.050 | LH ring / C#
2 | 9.625 |  | 0.124 | 0.050 | LH middle / B
1 (top, nearest reed) | 10.530 |  | 0.090 | 0.050 | LH index / Low A
Thumb (back side) | 11.250 |  | 0.075 | 0.040 | LH thumb (back) / High A overblow
← ALL POSITIONS NOW MEASURED (2026-05-02). Holes 4 & 6 are slightly smaller than their neighbors — likely for tuning fine-adjustment.
← Hole spacing pattern: 1.37, 1.17, 0.75, 1.10, 0.91, 0.91" — wider spacing at bottom (bigger notes), tighter at top (smaller notes).
PROTOTYPE WOODS (affordable alternatives to African Blackwood)
Wood | Density (lb/ft3) | Janka (lbf) | Acoustic Match | Cost (bf) | Notes
African Blackwood (reference) | 79 | 3670 | 5/5 reference | $50-100/bf | Gold standard; extremely hard, dense. Very expensive.
Ipe (Lapacho) - Tony has this! | 69 | 3510 | 4/5 excellent | $8-15/bf | Very hard, dense, oily. Great bore stability. Best value prototype.
Cocobolo | 69 | 2960 | 5/5 closest | $20-40/bf | Closest to Blackwood acoustically. Allergenic dust!
Honduran Rosewood | 64 | 2900 | 4/5 proven | $15-30/bf | Traditional pipe-making wood. Slightly less dense.
Hard Maple | 44 | 1450 | 3/5 lighter | $4-8/bf | Good for learning. Many practice chanters are maple.
Boxwood (European) | 57 | 2840 | 4/5 historical | $15-25/bf | Traditional for historical pipes. Hard to find as blanks.
Delrin / Acetal (plastic) | 89 | N/A | 3/5 modern | $3-6/bf equiv | Many modern practice chanters are Delrin. Machines perfectly. CNC ideal.
Cherry | 35 | 950 | 2/5 soft | $4-8/bf | Too soft for final pipe but GREAT for learning the reaming workflow.
Black Walnut | 38 | 1010 | 2/5 soft | $5-10/bf | You know this from NAF builds. Good for process practice.
RECOMMENDATION: #1 Cherry or Walnut ($5). #2 Ipe ($12). #3 Ipe or Cocobolo for keeps.
2. DRONES — Cylindrical Bore, Single Reed, Stopped Pipe (f = c / 4L)
Drone | Pitch | Freq (Hz) | Acoustic L (in) | Sections | Physical Dims
Tenor #1 | A3 (1 oct below) |  |  | Bottom 8" + Top 9" | Bore: bottom 11/32", top 9/16"; tuning chamber 3" deep
Tenor #2 | A3 (unison w/ #1) |  |  | Bottom 8" + Top 9" | Identical to Tenor #1; both tune to same pitch
Bass | A2 (2 oct below) |  |  | Bottom 8" + Mid 15" + Top 9" | Bore: bottom 3/8", mid 7/16", top 5/8"; extra mid section
DRONE BORE DETAIL (blue = adjustable inputs)
Drone Part | Length (in) | Bore ID (in) | Stock Bore (in) | Material
Tenor bottom | 8 | 0.344 | 0.813 | African Blackwood
Tenor top | 9 | 0.563 |  | African Blackwood + imitation ivory mounts
Tenor tuning chamber | 3.125 | 0.625
Bass bottom | 8 | 0.375 | 0.813
Bass middle | 15 | 0.438
Bass top | 9 | 0.625
3. REEDS
Reed Type | Construction | Dimensions | Material | Bridle | Notes
Chanter (double) | Two cane blades bound to metal staple | Staple: 1.25" long, 0.20" OD; blades: 0.50" wide | Arundo donax cane + copper staple | Waxed hemp binding | BUY these first; making requires years of skill
Tenor drone (single) | Single tongue on cylindrical body | Overall: 4" long, 3/8" OD; tongue: 1" long | Cane or synthetic (Ezeedrone, Kinnaird) | Rubber or waxed hemp; controls pitch | Seat diam: match your drone reed seat bore
Bass drone (single) | Single tongue on cylindrical body | Overall: 5.8" long, 1/2" OD; tongue: 2.5" long | Cane or synthetic | Rubber or waxed hemp; + pitch screw | Longer tongue = more air demand
4. BAG, BLOWPIPE & STOCKS
Component | Spec | Material | CNC/Lathe Notes
Bag | ~18x12" deflated; 600-800 in³ inflated; 5 stock holes | Synthetic (Gore-Tex zipper bag) or sheepskin | Buy ready-made; sewing requires specialized patterns
Blowpipe | 10-12" long, 1/2" bore, one-way valve at bag end | Blackwood or Delrin; imitation ivory mouthpiece | CNC lathe: straight bore + tenon + mount
Blowpipe valve | Flap or ball check valve inside blowpipe | Leather flap or rubber ball | Prevents air backflow when breathing
Chanter stock | 3" long, bore matches chanter sole; tie-in groove | Blackwood | CNC lathe: bore + external profile + groove for tying
Drone stocks (3) | 3" long each; bore ~13/16"; tie-in groove | Blackwood | All 3 identical; single stock for all 3 drones possible
Blowpipe stock | 2.5" long; bore matches blowpipe; tie-in groove | Blackwood | Same lathe setup as other stocks
BILL OF MATERIALS
# | Item | Qty | Spec | Source | Est. Cost
1 | African Blackwood blanks (chanter) | 1 | 2x2x16" min; kiln-dried, straight grain | Gilmer Wood, Bell Forest, Cook Woods | $40-80
2 | African Blackwood blanks (drones) | 7 | 2x2x10" (4 tops+bottoms) + 2x2x16" (bass mid) | Same; or substitute Cocobolo, Delrin | $150-350
3 | African Blackwood blanks (stocks) | 5 | 2x2x4" each for 5 stocks | Same source | $30-60
4 | Blowpipe blank + mouthpiece | 1 | 2x2x14" Blackwood + Delrin/ivory mouthpiece tip | Same; mouthpiece from bagpipe supplier | $20-40
5 | Bag (synthetic) | 1 | Bannatyne, Canmore, or Ross hybrid | Henderson's, National Piping Centre shop | $80-120
6 | Chanter reed (double) | 3 | Cane chanter reeds; buy several to find a good one | G1, Chesney, Melvin, Husk | $15-25 each
7 | Drone reeds (single, set of 3) | 1 | Synthetic set: 2 tenor + 1 bass | Ezeedrone, Kinnaird, Canning | $40-80
8 | Imitation ivory mounts + ferrules | 1 | Set of projecting mounts (Delrin or bone) | Turn on lathe or buy from bagpipe supplier | $30-80
9 | Hemp (waxed, yellow) | 1 spool | For all joints; wax with beeswax | Any bagpipe supplier | $5-10
10 | Tapered reamer (13" chanter) | 1 | Single-flute: 0.13" to 0.87" taper | Custom ground, or Clarkson taper reamer + adapt | $50-150
11 | Cord, tassels, cover, bag cover | 1 | Tartan bag cover + silk cords + drone ribbons | Henderson's, NPC shop | $50-100
 | ESTIMATED TOTAL (full set from scratch) |  |  |  | $555-1,170
BUILD METHOD
Phase 1: CHANTER (most critical; start here)
1. Turn exterior profile on lathe from Blackwood blank (2x2x16")
2. Step-drill the conical bore with increasing twist drills (1/8" up to 13/16")
3. Ream bore with tapered reamer to final cone (0.157" throat to 0.800" bell). CRITICAL: straight bore, no wander.
4. Drill 8 finger holes per scale table above. Start undersized, enlarge to tune.
5. Turn reed seat tenon at top. Fit with test reed; tune all notes with tape.
Phase 2: DRONES (tenor first, then bass)
6. Turn 2 tenor bottoms + 2 tenor tops from 2x2x10" blanks each.
7. Bore cylindrical: bottom 11/32", top 9/16" with tuning chamber 5/8" x 3" deep.
8. Turn bass bottom, middle, and top. Bore: 3/8", 7/16", 5/8" respectively.
9. Turn tuning slides (tenon/socket joints between sections). Fit with hemp for airtight seal.
10. Turn bell caps with sound holes matching tuning chamber bore.
Phase 3: STOCKS & BLOWPIPE
11. Turn 5 stocks (chanter, blowpipe, 3 drone) with tie-in grooves for bag attachment.
12. Turn blowpipe with straight 1/2" bore; install one-way valve (leather flap or check ball).
Phase 4: MOUNTS & FINISH
13. Turn imitation ivory (Delrin) projecting mounts, ferrules, and caps for all sections.
14. Finish all wood with multiple coats of shellac; polish. Metal combing rings optional.
Phase 5: ASSEMBLY
15. Tie stocks into bag using waxed hemp + zip ties (synthetic bag) or waxed thread (skin bag).
16. Insert reeds: chanter reed into chanter stock, drone reeds into drone stocks. Hemp for airtight seat.
17. Assemble all sections with hemp wrapping on tenons. Season bag + test for leaks.
18. Tune: Start with drones (tenors first, then bass) to match Low A. Fine-tune chanter with tape.
DESIGN NOTES
1. THE CHANTER BORE IS EVERYTHING. A conical bore that wanders even 0.01" off-center will produce a chanter that cannot be tuned.
2. START WITH A PRACTICE CHANTER. Same bore geometry at ~70% scale, no bag needed. This validates your reaming and hole drilling before committing to the full set.
3. CNC ADVANTAGE: Your ShopBot can CNC the exterior profiles precisely. Bore reaming must still be done on the lathe with a hand-guided tapered reamer.
4. DELRIN/POLYPENCO ALTERNATIVE: Much easier to machine than Blackwood, waterproof, dimensionally stable. Many professional pipe bands use Polypenco chanters.
5. JUST INTONATION: The GHB does NOT use equal temperament. The D and G are tuned to the 4th and harmonic 7th of A, which are noticeably different from piano tuning.
6. DRONE HARMONICS: The stopped-pipe drone produces predominantly odd harmonics (1st, 3rd, 5th). These must align with the chanter's open-pipe harmonics for the pipes to sound 'right'.
7. BAG PRESSURE: 18-25" water column (~0.6-0.9 psi). Higher pressure = sharper pitch. Consistent arm pressure is what makes a good piper.
8. REED SUPPLY: Buy commercial reeds for your first set. Chanter reed making is a lifelong apprenticeship. Drone reeds (synthetic) are plug-and-play.
9. COST VS. BUY: A student GHB set costs $700-1,500. A professional set costs $2,000-5,000+. Building from scratch at $555-1,170 is competitive with student sets but with custom quality.
10. YOUR MINNEAPOLIS BACKGROUND: You already know the fingering, the embellishments, and the sound you're chasing. That's 90% of the battle. The woodworking is the easy part for you.
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

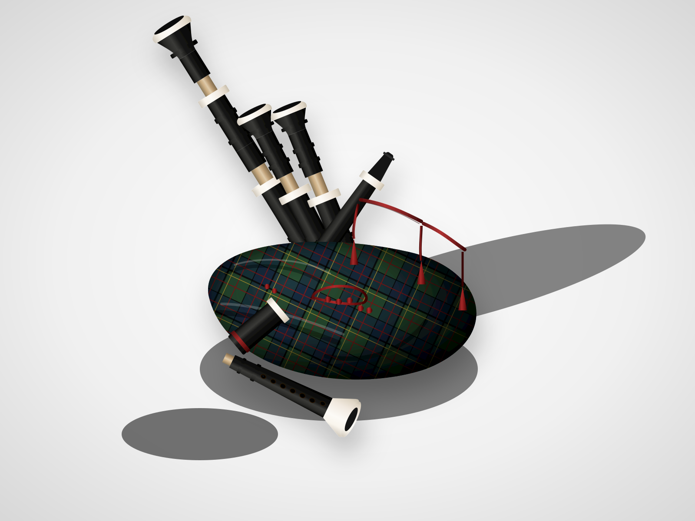
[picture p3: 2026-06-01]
images/hero-render.png

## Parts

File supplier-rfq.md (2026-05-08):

# Supplier RFQ - Great Highland Bagpipe Prototype

Hello,

I am sourcing parts and blanks for a first-pass Great Highland Bagpipe prototype
build. Please quote current price, availability, lead time, and shipping for the
items below. Substitutions are welcome if they preserve the stated critical
dimensions and material behavior.

## Quote Items

| Item | Required spec | Quantity | Notes |
| --- | --- | ---: | --- |
| Chanter blank | African blackwood or comparable dense stable turning blank, 2 x 2 x 16 in minimum | 1 | Straight grain, kiln dried, no checks |
| Drone blanks | Dense stable turning blanks, 2 x 2 x 10 in and 2 x 2 x 16 in | 7 | For two tenors and one bass drone |
| Stock blanks | 2 x 2 x 4 in turning blanks | 5 | Can be blackwood or Delrin |
| Delrin/acetal rod | Black acetal rod, 2 in diameter | quote lengths | Prototype alternative for chanter, drones, stocks |
| Synthetic bag | Highland bagpipe synthetic zipper bag, five stock layout | 1 | Please specify size and stock-hole layout |
| Chanter reeds | Medium Highland chanter reeds | 3 | Mixed strengths acceptable |
| Drone reeds | Synthetic set: two tenor, one bass | 1 set | Include adjustment instructions if available |
| Blowpipe valve | Flap or ball one-way valve | 1 | Compatible with Highland blowpipe |
| Waxed hemp | Yellow waxed hemp and beeswax | 1 spool | For joints and reed seats |
| Imitation ivory mounts | Delrin or bought mount/ferrule set | 1 set | Optional for prototype |

## Critical Questions

1. What are the actual dimensions and tolerances of the reed bodies/staples?
2. Does the synthetic bag ship with stock collars or tie-in instructions?
3. Are blackwood blanks waxed, kiln-dried, and suitable for long-bore turning?
4. Are substitutions available in Delrin/acetal for prototype work?
5. What is the current lead time and return policy for reeds?

Thank you.

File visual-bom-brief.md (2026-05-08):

# Visual BOM Brief

## Goal

Create a single-page visual BOM that helps a builder see the entire bagpipe as
an interacting pressure/reed/bore system before opening the spreadsheet.

## Required Panels

1. Full system hero: bag, chanter, two tenor drones, bass drone, blowpipe, and
   five stocks labeled.
2. Chanter exploded view: reed, reed seat, conical bore, tone holes, sole.
3. Drone exploded view: reed, bottom, tuning slide, top, cap/sound exit.
4. Bag interface: stock tie-ins, blowpipe valve, pressure path.
5. Maintenance parts: hemp, beeswax, spare reeds, manometer, tuner.

## Image Requirements

- Replace the current SVG system map with shop photos once parts exist.
- Photograph each reed next to calipers before fitting.
- Photograph one hemped joint before and after wax compression.
- Include a manometer photo during the pressure validation test.
- Avoid mood-board imagery; every image should identify a physical part or
  validation step.

## Layout

- Black-on-white shop-packet version.
- Separate recruiter/site version with the same labels and a single hero image.
- Every part label must map back to `bom.csv` item IDs.

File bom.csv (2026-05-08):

item_id | assembly | part | qty | material_spec | operation | source_or_supplier | search_terms | substitute_rule | drawing_ref | estimated_cost | notes
BOM-001 | Chanter | Full chanter blank | 1 | African blackwood 2x2x16 in minimum; prototype in ipe Delrin cherry or walnut | Turn exterior; bore; ream; drill holes | Gilmer Wood; Bell Forest; Cook Woods | African blackwood turning blank 2x2x18 | Use Delrin or ipe for first prototype; avoid final blackwood until bore workflow is proven | drawings/ghb-chanter-front.svg | 40-80 | Workbook recommends cheaper practice material first
BOM-002 | Drones | Tenor drone section blanks | 4 | African blackwood or Delrin 2x2x10 in | Turn; bore; tenon/socket; hemp slides | Gilmer Wood; Bell Forest; Cook Woods; plastics supplier | blackwood drone blank Delrin rod 2 inch | Build one tenor first then duplicate after validation | drawings/ghb-drone-set.svg | 80-180 | Two bottoms and two tops
BOM-003 | Drones | Bass drone section blanks | 3 | African blackwood or Delrin 2x2x10 and 2x2x16 in | Turn; bore; tenon/socket; hemp slides | Gilmer Wood; Bell Forest; Cook Woods | blackwood bass drone blank | Use Delrin for geometry proof if blackwood cost is limiting | drawings/ghb-drone-set.svg | 70-170 | Bottom middle and top sections
BOM-004 | Stocks | Stock blanks | 5 | African blackwood or Delrin 2x2x4 in | Turn bore and tie-in groove | Same as wood/plastic supplier | bagpipe stock blank Delrin blackwood | All stocks can be prototype Delrin for serviceability | drawings/ghb-pressure-interface.svg | 30-60 | Chanter stock blowpipe stock and three drone stocks
BOM-005 | Blowpipe | Blowpipe blank and mouthpiece | 1 | Blackwood or Delrin body with plastic mouthpiece | Turn straight bore and valve seat | Bagpipe supplier or plastics supplier | bagpipe blowpipe mouthpiece valve | Buy valve/mouthpiece if turning body only | drawings/ghb-pressure-interface.svg | 20-40 | Includes one-way valve interface
BOM-006 | Bag | Synthetic zipper bag | 1 | Bannatyne Canmore Ross or equivalent | Buy ready-made; tie in stocks | Henderson's; National Piping Centre shop | synthetic highland bagpipe bag zipper | Use synthetic for first validation because leak behavior is repeatable | images/ghb-system-map.svg | 80-120 | Actual price/date must be checked before purchase
BOM-007 | Reeds | Chanter reeds | 3 | Cane double reeds | Fit and test | G1; Chesney; Melvin; Husk | highland bagpipe chanter reed medium | Buy multiple strengths; do not make first reeds | validation.csv | 45-75 | Reed selection dominates response
BOM-008 | Reeds | Synthetic drone reed set | 1 | Two tenor plus one bass synthetic set | Fit; tune bridles/screws | Ezeedrone; Kinnaird; Canning | highland bagpipe synthetic drone reeds set | Cane reeds optional after system is stable | validation.csv | 40-80 | Reduces prototype variability
BOM-009 | Hardware | Hemp and beeswax | 1 spool | Waxed yellow hemp plus beeswax | Wrap joints and reed seats | Bagpipe supplier | waxed hemp bagpipe beeswax | None; fit depends on hemp | assembly-manual.md | 5-10 | Track compression during 24-hour retest
BOM-010 | Decorative mounts | Imitation ivory mounts and ferrules | 1 set | Delrin imitation ivory or nickel silver | Turn or buy; polish; optional engraving | Bagpipe supplier or plastics supplier | bagpipe projecting mounts imitation ivory | Prototype may omit decoration | drawings/ghb-drone-set.svg | 30-80 | Decoration must not block service access
BOM-011 | Tooling | Chanter tapered reamer | 1 | 0.13 to 0.87 in taper approx | Buy custom or grind; use with lathe support | Custom toolmaker or woodwind tool supplier | bagpipe chanter reamer tapered | No safe substitute for final bore; prototype can use measured stepped tests | drawing-brief.md | 50-150 | High-risk tool
BOM-012 | Accessories | Cord tassels and cover | 1 set | Tartan cover cords ribbons | Buy after prototype plays | Bagpipe supplier | highland bagpipe cover cord tassels | Optional during acoustic validation | visual-bom-brief.md | 50-100 | Keep out of first acoustic tests

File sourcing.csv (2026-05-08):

component | required_spec | preferred_supplier | search_terms | date_checked | price_each | lead_time | substitutions | risk_notes
Chanter blank | 2x2x16 in dense stable turning blank African blackwood or prototype material | Gilmer Wood; Bell Forest; Cook Woods | African blackwood 2x2x18 turning blank |  |  | Ipe Delrin hard maple cherry walnut | Blackwood is expensive and can crack or move if poorly dried
Drone blanks | 2x2 in dense stable blanks in 10 and 16 in lengths | Gilmer Wood; Bell Forest; Cook Woods | African blackwood bagpipe drone blank |  |  | Delrin or cocobolo | Seven drone pieces create cost and yield risk
Delrin rod | 2 in acetal/Delrin rod for prototype chanter drones and stocks | Industrial plastic supplier | 2 inch black acetal rod Delrin |  |  | Blackwood after geometry proof | Dimensionally stable but less traditional tone/feel
Synthetic bag | Highland bagpipe synthetic zipper bag with five stock positions | Henderson's; National Piping Centre; bagpipe shops | Bannatyne Canmore Ross synthetic bagpipe bag |  |  | Sheepskin or hybrid bag | Supplier sizing and stock-hole layout must match plan
Chanter reeds | Medium-strength Highland chanter reeds three-count mix | G1; Chesney; Melvin; Husk | highland bagpipe chanter reed medium |  |  | Buy mixed strengths from two makers | Single reed choice can make the chanter appear wrong
Drone reeds | Synthetic set with two tenors and one bass | Ezeedrone; Kinnaird; Canning | highland bagpipe synthetic drone reeds set |  |  | Cane drone reeds later | Synthetic dimensions may drive reed seat sizing
Waxed hemp | Yellow waxed hemp and beeswax | Bagpipe supplier | waxed hemp bagpipe beeswax |  |  | None | Joint fit depends on wrap quality and compression over time
Blowpipe valve | One-way blowpipe valve leather flap or ball valve | Bagpipe supplier | bagpipe blowpipe valve replacement |  |  | Buy complete blowpipe for reference | Air backflow makes pressure validation impossible
Mount material | Imitation ivory Delrin rod or bought projecting mounts | Bagpipe supplier; plastics supplier | bagpipe imitation ivory mounts Delrin rod |  |  | Omit on prototype | Decoration can consume budget before acoustic risk is retired
Custom reamer | Chanter taper reamer matching bore plan | Woodwind toolmaker or custom grinder | bagpipe chanter reamer custom tapered |  |  | Prototype step-bore test only | Incorrect taper can ruin every chanter attempt

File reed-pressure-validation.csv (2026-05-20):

check_id | subsystem | reed_source_role | pressure_gate | target_or_observation | method | measurement_required | authority_status | next_action
RP-001 | chanter | commercial double chanter reed | reed_seat_static_fit | Staple seats airtight without wobble before bag pressure tests | dry fit reed in chanter seat; check wobble, insertion depth, and leak path | true | measurement_required | Record reed maker, strength, staple OD, seat depth, and leak result before tone-hole tuning.
RP-002 | chanter | commercial double chanter reed | onset_pressure | Low A speaks cleanly as pressure rises toward first playable threshold | manometer plus tuner; increase bag pressure slowly from no-sound to speaking | true | measurement_required | Log onset pressure, pitch, warble, and any chirp before changing holes or reed.
RP-003 | chanter | commercial double chanter reed | normal_play_pressure | Low A and scale notes remain stable across the planned 18-25 inH2O normal range | hold 18, 21, and 25 inH2O; record frequency and cents error for Low A plus representative scale notes | true | measurement_required | Use results to decide whether reed strength or hole tuning is the next variable.
RP-004 | chanter | commercial double chanter reed | cutoff_pressure | Reed overblow/cutoff threshold is above the chosen normal-play pressure | raise pressure past normal range only enough to identify cutoff or instability | true | measurement_required | Do not tune permanent holes until cutoff margin is known.
RP-005 | tenor_drone | synthetic tenor drone reed | onset_and_restart | Reference tenor starts and restarts predictably before duplicating the second tenor | cycle bag pressure down/up through onset; record start pressure, restart pressure, and bridle/screw setting | true | measurement_required | Validate one tenor reed and slide range before copying GHB-TENOR-2.
RP-006 | tenor_drone | synthetic tenor drone reed | normal_play_pressure | Tenor drone holds A3 without sudden pitch jumps across the planned pressure range | record Hz/cents at 18, 21, and 25 inH2O with slide position and reed setting | true | measurement_required | Adjust reed first, then slide; do not cut wood to correct pressure instability.
RP-007 | bass_drone | synthetic bass drone reed | onset_and_cutoff | Bass drone starts below normal play pressure and remains stable through normal play | record onset, normal-play pitch, cutoff/choke pressure, slide position, and reed setting | true | measurement_required | Run after tenor reference passes; bass dimensions remain provisional until this row has evidence.
RP-008 | full_set | coupled chanter plus drone reeds | coupled_pressure_response | Adding chanter to tuned drones does not collapse pressure, beat excessively, or force reed retuning | test drones alone, then drones plus chanter at the same manometer targets | true | measurement_required | Only promote coupled tuning claims after this full-set row has measured evidence.
RP-009 | bag_and_valve | no reed pressure source | pressure_hold_control | Bag, stocks, and blowpipe valve hold pressure well enough that reed results are meaningful | 60-second pressure decay test before reeds are installed; repeat after stocks and reeds are fitted | true | measurement_required | Fix leaks before interpreting any reed onset, cutoff, or tuning response.

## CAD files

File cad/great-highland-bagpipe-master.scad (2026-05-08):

// Great Highland Bagpipe parametric starter.
// This is a visual/layout master, not a replacement for measured reed-seat CAD.

$fn = 72;

chanter_len = 14.5;
chanter_top_od = 0.88;
chanter_bell_od = 1.25;

tenor_bottom_len = 8;
tenor_top_len = 9;
bass_bottom_len = 8;
bass_middle_len = 15;
bass_top_len = 9;

inch = 25.4;

module pipe_section(len_in, od_in, bore_in, label_offset=0) {
  difference() {
    cylinder(h=len_in*inch, d=od_in*inch);
    translate([0,0,-1]) cylinder(h=len_in*inch+2, d=bore_in*inch);
  }
}

module chanter() {
  difference() {
    cylinder(h=chanter_len*inch, d1=chanter_bell_od*inch, d2=chanter_top_od*inch);
    translate([0,0,-1]) cylinder(h=chanter_len*inch+2, d1=0.800*inch, d2=0.157*inch);
  }
}

module tenor_drone() {
  pipe_section(tenor_bottom_len, 0.95, 0.344);
  translate([0,0,tenor_bottom_len*inch + 8])
    pipe_section(tenor_top_len, 0.95, 0.563);
}

module bass_drone() {
  pipe_section(bass_bottom_len, 1.05, 0.375);
  translate([0,0,bass_bottom_len*inch + 8])
    pipe_section(bass_middle_len, 1.05, 0.438);
  translate([0,0,(bass_bottom_len+bass_middle_len)*inch + 16])
    pipe_section(bass_top_len, 1.05, 0.625);
}

translate([-80,0,0]) chanter();
translate([0,0,0]) tenor_drone();
translate([45,0,0]) tenor_drone();
translate([95,0,0]) bass_drone();

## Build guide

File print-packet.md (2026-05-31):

# Great Highland Bagpipe Capstone Print Packet

Generated: 2026-05-08
Packet folder: `/mnt/c/Users/Tony/Documents/GitHub/great-highland-bagpipe`

## File Map

| File | Purpose |
| --- | --- |
| `design.md` | Project intent, catalog metadata, assumptions, and validation plan. |
| `bom.csv` | Starter bill of materials with part categories, quantities, drawing refs, and notes. |
| `sourcing.csv` | Supplier/search tracker with specs, price/date fields, lead time, substitutes, and risks. |
| `cut-list.csv` | Rough/final stock sizes, material, grain/orientation, operations, yield, and offcuts. |
| `drawing-brief.md` | Manufacturing drawing and technical product sketch brief. |
| `assembly-manual.md` | Shop-facing sequence, tools, fixtures, safety, tuning, finishing, and maintenance notes. |
| `validation.csv` | Target/measured values, tolerance, environment, result, and tuning/build action log. |
| `supplier-rfq.md` | Supplier email/request-for-quote starter. |
| `visual-bom-brief.md` | Art direction for an image-forward visual BOM. |
| `great-highland-bagpipe-starter.wl` | Wolfram starter for physics, optimization, visualization, and validation. |
| `README.md` | Project artifact. |
| `family-spec.csv` | Project artifact. |
| `photo-shotlist.md` | Project artifact. |
| `risks.md` | Project artifact. |

## design.md

Project intent, catalog metadata, assumptions, and validation plan.

# Great Highland Bagpipe Build Packet

## Intent

Build a first-pass engineering packet for a complete Great Highland Bagpipe set
that exposes the system interactions: chanter bore and reed, drones and drone
reeds, bag pressure, stocks, blowpipe valve, tuning slides, sourcing,
maintenance, and validation. The goal is not to claim a finished concert-grade
set from formulas alone; it is to define the measured build loop that gets from
workbook geometry to a playable, serviceable prototype.

## Catalog Metadata

| Field | Value |
| --- | --- |
| Instrument ID | GHB-001 |
| Slug | great-highland-bagpipe |
| Family | reed |
| Pipeline | cnc-lathe |
| Reference workbook | `great-highland-bagpipe-design-table.xlsx` |
| Done-bar family | reed woodwinds, closest local sisters: `chalumeau`, `duduk` |
| Date | 2026-05-08 |

## Design Inputs

| Parameter | Workbook value | Notes |
| --- | ---: | --- |
| Chanter Low A | 480 Hz | Modern GHB pitch, not A440 concert pitch |
| Speed of sound | 13510 in/s | Workbook value, roughly room-temperature air |
| Chanter scale | Mixolydian-like, just intonation | Tuned to drones, not equal temperament |
| Wood reference | African blackwood | Ipe, cocobolo, Delrin, maple, cherry, walnut are prototype alternatives |
| Drone tuning | two A3 tenors, one A2 bass | Tenors one octave below Low A; bass two octaves below |
| Bag pressure | 18-25 inH2O first-pass range | Pressure changes reed pitch and stability |

## Governing Model

The Great Highland Bagpipe is a coupled reed/resonator/reservoir system. The
packet intentionally uses different first-order models for different
subsystems, then validates the coupled result under pressure.

### Chanter

The chanter is a conical bore driven by a double reed. A conical reed pipe
behaves closer to an open-open pipe for pitch than a cylindrical stopped pipe,
but tone holes, reed compliance, and bore taper dominate the final intonation.
The workbook dimensions and measured practice-chanter hole positions are the
starting geometry.

```text
f_chanter ~= c / (2 * L_eff)
L_eff ~= c / (2 * f_target)
c = speed of sound in inches per second
```

Worked example from the workbook:

```text
Low A = 480 Hz
c = 13510 in/s
L_eff = 13510 / (2 * 480) = 14.073 in
Workbook physical full chanter length = 14.5 in
```

The difference between effective and physical length is expected because the
reed seat, conical end behavior, bell flare, and tone-hole network all shift the
effective acoustic length. Final tuning must start with undersize holes and
open them by measurement.

### Drones

The drones are cylindrical single-reed pipes, closed at the reed end and open at
the top. They are first-pass stopped pipes with odd-harmonic emphasis.

```text
f_drone ~= c / (4 * L_eff)
L_eff ~= c / (4 * f_target)
```

Worked examples from the workbook:

```text
Tenor drone A3 = 240 Hz
L_eff = 13510 / (4 * 240) = 14.073 in

Bass drone A2 = 120 Hz
L_eff = 13510 / (4 * 120) = 28.146 in
```

The workbook's physical sections intentionally exceed or subdivide these
effective lengths because tuning chambers, hemped slides, reed seats, and cap
geometry move the acoustic endpoint.

### Bag Pressure And Reeds

The bag is a pressure reservoir, not just a container. The reed only oscillates
inside a stable pressure window. Pressure changes can sharpen or destabilize
the chanter and drones, so every tuning row in `validation.csv` includes
environment and pressure notes.

```text
cents_error = 1200 * log2(measured_hz / target_hz)
pressure_target = 18-25 inH2O for first prototype testing
```

### Empirical Correction Guard

No Native American flute K2 correction is applied here. This packet uses
first-order conical/stopped-pipe estimates plus measured GHB-specific
validation rows. Any future correction must be derived from measured chanter,
drone, reed, and pressure data from this family.

## Chanter Scale Table

| Note | Ratio to Low A | Target Hz at Low A 480 | Model L_eff in | Prototype action |
| --- | ---: | ---: | ---: | --- |
| Low G | 8/9 | 426.67 | 15.832 | Validate as cross/fingering-dependent low note |
| Low A | 1/1 | 480.00 | 14.073 | Establish reed strength and pressure first |
| B | 9/8 | 540.00 | 12.509 | Drill undersize, tape-tune up |
| C written C# | 5/4 | 600.00 | 11.258 | Drill undersize, tune against drones |
| D | 4/3 | 640.00 | 10.555 | Check just fourth against drones |
| E | 3/2 | 720.00 | 9.382 | Watch high hand spacing and hole size |
| F written F# | 5/3 | 800.00 | 8.444 | Small tuning changes are sensitive |
| High G | 7/4 | 840.00 | 8.042 | Treat as cross-fingering/harmonic validation |
| High A | 2/1 | 960.00 | 7.036 | Validate as octave behavior, not a simple hole row |

## Subsystem Interfaces

| Interface | Critical fit | Validation |
| --- | --- | --- |
| Chanter reed to chanter seat | Airtight staple fit, stable blade opening | Reed seats without wobble; Low A speaks at target pressure |
| Chanter stock to bag | Stock tie-in and hemp seal | No bubbles in leak test |
| Drone reed to drone seat | Reed body matches seat diameter | Reed starts, cuts off, and restarts predictably |
| Drone slides | Hemped tenon/socket with tuning travel | Smooth movement, no air loss, no sudden pitch jumps |
| Blowpipe valve | One-way seal | Bag holds pressure when player stops blowing |
| Bag to stocks | Mechanical tie-in | 60-second pressure hold test |

## Hardware Alignment

| Operation | Tooling | Fixture | Notes |
| --- | --- | --- | --- |
| Chanter exterior turning | Lathe roughing/detail tools | Between centers, then chuck/collet | Leave extra length for holding and trimming |
| Chanter conical bore | Step drills plus custom tapered reamer | Headstock-driven deep bore setup | Bore straightness is a high-risk acoustic variable |
| Tone holes | Drill press or mill, undersize bits | V-block indexed to front/back datum | Open by reaming/sanding while measuring pitch |
| Drone cylindrical bores | Long brad-point/twist drills, reamers | Lathe center drilling and steady rest | Build one tenor as process proof |
| Tuning slides | Lathe turning and parting tools | Matched tenon/socket gauges | Hemp clearance must be planned, not guessed |
| Stocks | Lathe boring tools | Batch fixture for repeated stock bodies | Tie-in groove must not cut too deep |
| Mounts/ferrules | Lathe, optional laser engraving | Mandrels for Delrin/ferrule rings | Keep decorative parts removable in prototype |

## Build Strategy

Prototype order is deliberately reeds-first and pressure-first:

1. Buy three chanter reeds and one synthetic drone reed set.
2. Buy a synthetic zipper bag and blowpipe valve before final tuning work.
3. Build a practice/prototype chanter in cherry, walnut, ipe, or Delrin.
4. Validate bore, reed, and hole tuning before building African blackwood.
5. Build one tenor drone, then duplicate it after measured success.
6. Build the bass drone after slide and reed behavior are stable.
7. Tie in stocks, run leakage tests, and maintain a tuning/pressure log.

## Assumptions And Unknowns

| Item | Status | Why it matters |
| --- | --- | --- |
| Chanter bore station table | Derived from workbook and practice measurements | Final intonation needs measured stations, not only a linear cone |
| Reed brand/strength | Unknown until purchased | Reed compliance changes pitch, pressure, and response |
| Bag actual volume | Supplier-dependent | Affects stability and ergonomic squeeze behavior |
| Drone reed seat dimensions | Must match chosen reeds | Synthetic reed body diameters vary |
| Final decorative mount dimensions | Flexible | Do not let ornament drive acoustic or service dimensions |

## Validation Plan

Validation starts with the subsystem, then moves to the coupled system:

1. Bench leak test every stock, reed seat, slide, and bag tie-in.
2. Measure pressure at start, normal play, and cut-off for chanter and drones.
3. Tune drones without the chanter, then add chanter and listen for beating.
4. Record note frequency, cents error, pressure, temperature, humidity, reed,
   and corrective action in `validation.csv`.
5. Repeat after 24 hours to catch hemp compression, bag leakage, and moisture
   effects.

## bom.csv

Starter bill of materials with part categories, quantities, drawing refs, and notes.

| item_id | assembly | part | qty | material_spec | operation | source_or_supplier | search_terms | substitute_rule | drawing_ref | estimated_cost | notes |
| --- | --- | --- | --- | --- | --- | --- | --- | --- | --- | --- | --- |
| BOM-001 | Chanter | Full chanter blank | 1 | African blackwood 2x2x16 in minimum; prototype in ipe Delrin cherry or walnut | Turn exterior; bore; ream; drill holes | Gilmer Wood; Bell Forest; Cook Woods | African blackwood turning blank 2x2x18 | Use Delrin or ipe for first prototype; avoid final blackwood until bore workflow is proven | drawings/ghb-chanter-front.svg | 40-80 | Workbook recommends cheaper practice material first |
| BOM-002 | Drones | Tenor drone section blanks | 4 | African blackwood or Delrin 2x2x10 in | Turn; bore; tenon/socket; hemp slides | Gilmer Wood; Bell Forest; Cook Woods; plastics supplier | blackwood drone blank Delrin rod 2 inch | Build one tenor first then duplicate after validation | drawings/ghb-drone-set.svg | 80-180 | Two bottoms and two tops |
| BOM-003 | Drones | Bass drone section blanks | 3 | African blackwood or Delrin 2x2x10 and 2x2x16 in | Turn; bore; tenon/socket; hemp slides | Gilmer Wood; Bell Forest; Cook Woods | blackwood bass drone blank | Use Delrin for geometry proof if blackwood cost is limiting | drawings/ghb-drone-set.svg | 70-170 | Bottom middle and top sections |
| BOM-004 | Stocks | Stock blanks | 5 | African blackwood or Delrin 2x2x4 in | Turn bore and tie-in groove | Same as wood/plastic supplier | bagpipe stock blank Delrin blackwood | All stocks can be prototype Delrin for serviceability | drawings/ghb-pressure-interface.svg | 30-60 | Chanter stock blowpipe stock and three drone stocks |
| BOM-005 | Blowpipe | Blowpipe blank and mouthpiece | 1 | Blackwood or Delrin body with plastic mouthpiece | Turn straight bore and valve seat | Bagpipe supplier or plastics supplier | bagpipe blowpipe mouthpiece valve | Buy valve/mouthpiece if turning body only | drawings/ghb-pressure-interface.svg | 20-40 | Includes one-way valve interface |
| BOM-006 | Bag | Synthetic zipper bag | 1 | Bannatyne Canmore Ross or equivalent | Buy ready-made; tie in stocks | Henderson's; National Piping Centre shop | synthetic highland bagpipe bag zipper | Use synthetic for first validation because leak behavior is repeatable | images/ghb-system-map.svg | 80-120 | Actual price/date must be checked before purchase |
| BOM-007 | Reeds | Chanter reeds | 3 | Cane double reeds | Fit and test | G1; Chesney; Melvin; Husk | highland bagpipe chanter reed medium | Buy multiple strengths; do not make first reeds | validation.csv | 45-75 | Reed selection dominates response |
| BOM-008 | Reeds | Synthetic drone reed set | 1 | Two tenor plus one bass synthetic set | Fit; tune bridles/screws | Ezeedrone; Kinnaird; Canning | highland bagpipe synthetic drone reeds set | Cane reeds optional after system is stable | validation.csv | 40-80 | Reduces prototype variability |
| BOM-009 | Hardware | Hemp and beeswax | 1 spool | Waxed yellow hemp plus beeswax | Wrap joints and reed seats | Bagpipe supplier | waxed hemp bagpipe beeswax | None; fit depends on hemp | assembly-manual.md | 5-10 | Track compression during 24-hour retest |
| BOM-010 | Decorative mounts | Imitation ivory mounts and ferrules | 1 set | Delrin imitation ivory or nickel silver | Turn or buy; polish; optional engraving | Bagpipe supplier or plastics supplier | bagpipe projecting mounts imitation ivory | Prototype may omit decoration | drawings/ghb-drone-set.svg | 30-80 | Decoration must not block service access |
| BOM-011 | Tooling | Chanter tapered reamer | 1 | 0.13 to 0.87 in taper approx | Buy custom or grind; use with lathe support | Custom toolmaker or woodwind tool supplier | bagpipe chanter reamer tapered | No safe substitute for final bore; prototype can use measured stepped tests | drawing-brief.md | 50-150 | High-risk tool |
| BOM-012 | Accessories | Cord tassels and cover | 1 set | Tartan cover cords ribbons | Buy after prototype plays | Bagpipe supplier | highland bagpipe cover cord tassels | Optional during acoustic validation | visual-bom-brief.md | 50-100 | Keep out of first acoustic tests |

## sourcing.csv

Supplier/search tracker with specs, price/date fields, lead time, substitutes, and risks.

| component | required_spec | preferred_supplier | search_terms | date_checked | price_each | lead_time | substitutions | risk_notes |
| --- | --- | --- | --- | --- | --- | --- | --- | --- |
| Chanter blank | 2x2x16 in dense stable turning blank African blackwood or prototype material | Gilmer Wood; Bell Forest; Cook Woods | African blackwood 2x2x18 turning blank |  |  | Ipe Delrin hard maple cherry walnut | Blackwood is expensive and can crack or move if poorly dried |  |
| Drone blanks | 2x2 in dense stable blanks in 10 and 16 in lengths | Gilmer Wood; Bell Forest; Cook Woods | African blackwood bagpipe drone blank |  |  | Delrin or cocobolo | Seven drone pieces create cost and yield risk |  |
| Delrin rod | 2 in acetal/Delrin rod for prototype chanter drones and stocks | Industrial plastic supplier | 2 inch black acetal rod Delrin |  |  | Blackwood after geometry proof | Dimensionally stable but less traditional tone/feel |  |
| Synthetic bag | Highland bagpipe synthetic zipper bag with five stock positions | Henderson's; National Piping Centre; bagpipe shops | Bannatyne Canmore Ross synthetic bagpipe bag |  |  | Sheepskin or hybrid bag | Supplier sizing and stock-hole layout must match plan |  |
| Chanter reeds | Medium-strength Highland chanter reeds three-count mix | G1; Chesney; Melvin; Husk | highland bagpipe chanter reed medium |  |  | Buy mixed strengths from two makers | Single reed choice can make the chanter appear wrong |  |
| Drone reeds | Synthetic set with two tenors and one bass | Ezeedrone; Kinnaird; Canning | highland bagpipe synthetic drone reeds set |  |  | Cane drone reeds later | Synthetic dimensions may drive reed seat sizing |  |
| Waxed hemp | Yellow waxed hemp and beeswax | Bagpipe supplier | waxed hemp bagpipe beeswax |  |  | None | Joint fit depends on wrap quality and compression over time |  |
| Blowpipe valve | One-way blowpipe valve leather flap or ball valve | Bagpipe supplier | bagpipe blowpipe valve replacement |  |  | Buy complete blowpipe for reference | Air backflow makes pressure validation impossible |  |
| Mount material | Imitation ivory Delrin rod or bought projecting mounts | Bagpipe supplier; plastics supplier | bagpipe imitation ivory mounts Delrin rod |  |  | Omit on prototype | Decoration can consume budget before acoustic risk is retired |  |
| Custom reamer | Chanter taper reamer matching bore plan | Woodwind toolmaker or custom grinder | bagpipe chanter reamer custom tapered |  |  | Prototype step-bore test only | Incorrect taper can ruin every chanter attempt |  |

## cut-list.csv

Rough/final stock sizes, material, grain/orientation, operations, yield, and offcuts.

| part_id | assembly | qty | material | rough_dimensions_in | final_dimensions_in | grain_or_orientation | operation | yield_or_offcut_plan | notes |
| --- | --- | --- | --- | --- | --- | --- | --- | --- | --- |
| CUT-001 | Chanter | 1 | African blackwood or prototype Delrin/ipe/cherry | 2 x 2 x 16.5 | OD 0.88 reed seat to 1.25 bell; length 14.5 | Straight grain along bore; avoid defects | Turn exterior; drill/ream conical bore; drill tone holes | Save offcut for reed-seat and finish tests | Leave extra length until bore and reed seat are proven |
| CUT-002 | Tenor bottom sections | 2 | African blackwood or Delrin | 2 x 2 x 10 | 8.0 long; bore 0.344 nominal | Grain along bore | Turn; bore; make tenon/socket | Pair offcuts for slide gauges | Build first tenor bottom as setup proof |
| CUT-003 | Tenor top sections | 2 | African blackwood or Delrin | 2 x 2 x 10 | 9.0 long; bore 0.563 nominal | Grain along bore | Turn; bore; chamber; cap feature | Use matching offcuts for cap tests | Tenors should be identical after validation |
| CUT-004 | Bass bottom | 1 | African blackwood or Delrin | 2 x 2 x 10 | 8.0 long; bore 0.375 nominal | Grain along bore | Turn; bore; tenon/socket | Save bore plug sample | Validate before bass middle |
| CUT-005 | Bass middle | 1 | African blackwood or Delrin | 2 x 2 x 16 | 15.0 long; bore 0.438 nominal | Grain along bore | Turn; long bore; tenon/socket | Plan center-drill from both ends if needed | Highest long-bore wander risk |
| CUT-006 | Bass top | 1 | African blackwood or Delrin | 2 x 2 x 10 | 9.0 long; bore 0.625 nominal | Grain along bore | Turn; bore; chamber/cap feature | Use offcut for cap test | Match drone top visual language |
| CUT-007 | Stocks | 5 | African blackwood or Delrin | 2 x 2 x 4 each | 2.5-3.0 long; bore to mating part; tie-in groove | Grain along bore | Batch turn and bore | Make one extra stock blank | Groove depth must preserve wall strength |
| CUT-008 | Blowpipe | 1 | African blackwood or Delrin | 2 x 2 x 14 | 10-12 long; bore 0.5 nominal | Grain along bore | Turn; bore; valve seat; mouthpiece fit | Offcut for valve seat test | Valve must seal before full assembly |
| CUT-009 | Mounts/ferrules | 1 set | Delrin imitation ivory or nickel silver rod | As required by profile | Fit to each section | Neutral; avoid stress fit | Turn rings and ferrules | Prototype can omit | Do not glue permanently until tuning slides are proven |
| CUT-010 | Fixture gauges | 1 set | Hardwood or Delrin scraps | Shop offcuts | Reed seat gauges; tenon gauges; bore check plugs | Stable material | Turn gauges before final parts | Reuse across builds | Gauges reduce repeated measurement error |

## drawing-brief.md

Manufacturing drawing and technical product sketch brief.

# Drawing Brief

## Drawing Set

| Drawing | Purpose | Required datums |
| --- | --- | --- |
| `drawings/ghb-chanter-front.svg` | Chanter body, tone-hole datum chain, bore section | Datum A = sole/bell end, Datum B = reed seat axis, Datum C = front hole line |
| `drawings/ghb-drone-set.svg` | Tenor and bass section lengths, bores, tuning-slide interfaces | Datum A = reed seat end, Datum B = slide shoulder, Datum C = sound exit |
| `drawings/ghb-pressure-interface.svg` | Bag, stocks, blowpipe, valve, pressure path | Datum A = bag centerline, Datum B = stock tie-in groove |
| `drawings/ghb-system-validation.svg` | Validation flow: pressure, leak, drone tuning, chanter tuning, maintenance retest | Datum A = subsystem test order |

## Standards

- Units: inches with metric equivalents added later where useful.
- Default tolerance: +/-0.005 in for turned acoustic features; +/-0.015 in for
  decorative exterior features; fit-specific tolerances must be measured from
  purchased reeds and bag hardware.
- Critical dimensions must trace to `great-highland-bagpipe-design-table.xlsx`
  or measured supplier parts.
- Any reed-seat or stock dimension not measured yet is marked "measure chosen
  part" rather than guessed.

## Chanter Notes

The tone-hole coordinates in the workbook include measured practice-chanter
locations and first-pass target full-chanter values. The drawing must show
undersize drill diameters and leave final tuning by measurement.

## Drone Notes

Drone drawings must show effective acoustic length separately from physical
section length. Tuning slides, reed seats, and cap geometry move the acoustic
endpoint.

## assembly-manual.md

Shop-facing sequence, tools, fixtures, safety, tuning, finishing, and maintenance notes.

# Great Highland Bagpipe Assembly Manual

## Shop Principle

Do not build the ornate final set first. Bagpipes are a pressure-coupled reed
system; a beautiful bore that cannot be tuned with the chosen reeds is scrap.
Retire reed, pressure, and leakage risk before committing expensive blackwood.

## Tools And Fixtures

- Lathe with chuck/collet support, tailstock drill chuck, live center, and
  steady rest for long sections.
- Step-drill set, long bits, reamers, bore gauges, and a purpose-made chanter
  taper reamer.
- V-block or indexed drill fixture for chanter tone holes.
- Manometer for bag pressure.
- Calipers, small bore gauges, tuner, tape, beeswax, waxed hemp, and leak-test
  solution.
- Reed-seat and tenon/socket gauges turned from stable offcuts.

## Phase 0 - Buy The Coupling Parts

1. Buy at least three commercial chanter reeds before finalizing the reed seat.
2. Buy a synthetic drone reed set.
3. Buy or borrow a synthetic zipper bag and a blowpipe valve.
4. Measure reed body/staple diameters and update `validation.csv`.

## Phase 1 - Prototype Chanter

1. Rough-turn the blank oversized and leave holding allowance at both ends.
2. Establish the bore datum from the reed seat end.
3. Step-drill conservatively, then ream to the planned taper.
4. Turn the exterior only after the bore is confirmed straight enough.
5. Drill tone holes undersize using the datum plan in `drawing-brief.md`.
6. Fit a commercial reed and check Low A at stable pressure.
7. Use tape and incremental enlargement to bring the scale into range.

## Phase 2 - Tenor Drone Proof

1. Build one tenor drone bottom and top.
2. Bore the bottom and top to the workbook dimensions.
3. Turn the tuning slide with planned hemp clearance.
4. Fit a tenor drone reed and find the slide range for A3.
5. Log reed setting, pressure, temperature, and cents error.
6. Duplicate the validated tenor.

## Phase 3 - Bass Drone

1. Build the bass bottom, middle, and top as separate sections.
2. Use a steady rest and center-drill strategy for the long middle section.
3. Bore slightly conservatively where reaming or sanding is planned.
4. Fit the bass drone reed and confirm A2 with usable tuning travel.

## Phase 4 - Stocks, Bag, And Blowpipe

1. Batch-turn five stocks with tie-in grooves.
2. Turn the blowpipe body and fit the one-way valve.
3. Tie the stocks into the synthetic bag.
4. Leak-test each stock before inserting reeds or drones.
5. Assemble all pipes with hemped joints and repeat the leak test.

## Phase 5 - Tuning And Balancing

1. Tune both tenors together at stable pressure.
2. Add the bass drone and tune it against the tenors.
3. Add the chanter and tune Low A against the drone reference.
4. Work upward through the chanter notes, changing one variable at a time.
5. If pressure changes shift multiple notes together, correct pressure/reed
   behavior before changing hole geometry.

## Maintenance Loop

- Before each session: inspect reeds, check hemped joints, confirm blowpipe
  valve seal, and run a short pressure hold.
- After each session: dry moisture from blowpipe and stocks, inspect reed
  seats, and loosen any joint that became too tight.
- Weekly during prototype: repeat drone tuning and bag leak validation.
- After 24 hours: recheck pitch because hemp compression can change slide
  position and air leakage.

## Stop Conditions

Stop and redesign or rebuild the affected part if any of these occur:

- Chanter bore wander is visible or pitch errors cannot be corrected with hole
  size/tape.
- A stock tie-in leaks after two attempts.
- A tuning slide binds before reaching target pitch.
- A reed only speaks outside the expected pressure range.
- Any crack appears around a bore, stock groove, or slide socket.

## validation.csv

Target/measured values, tolerance, environment, result, and tuning/build action log.

| check_id | subsystem | target | formula_or_spec | predicted | measured | units | tolerance | environment | result | action |
| --- | --- | --- | --- | --- | --- | --- | --- | --- | --- | --- |
| VAL-001 | Reference | A4 sanity check | 440*2^((69-69)/12) | 440 |  | Hz | 0 | room | Pending | Confirms frequency formula implementation |
| VAL-002 | Chanter Low A | 480 Hz at stable pressure | c/(2*L_eff) | 480 |  | Hz | +/-10 cents at prototype stage | record temp humidity pressure | Pending | Set reed and pressure before hole tuning |
| VAL-003 | Chanter Low A effective length | c/(2*480) | 14.073 |  | in | +/-0.25 in first-order estimate | room | Pending | Compare with physical 14.5 in body and reed behavior |  |
| VAL-004 | Chanter scale all notes | Just ratios from design.md | c/(2*f_note) | see design.md |  | cents | +/-15 cents prototype; +/-5 cents final | record pressure and reed | Pending | Tune from undersize with tape/enlargement |
| VAL-005 | Tenor drone A3 | 240 Hz | c/(4*240) | 14.073 |  | in effective | +/-0.5 in before slide tuning | room | Pending | Check slide range before duplicate tenor |
| VAL-006 | Tenor drone frequency | 240 Hz with chosen reed | stopped pipe plus reed/slide | 240 |  | Hz | +/-5 cents against chanter Low A | record pressure and reed | Pending | Adjust reed bridle/screw then slide |
| VAL-007 | Bass drone A2 | 120 Hz | c/(4*120) | 28.146 |  | in effective | +/-1.0 in before slide tuning | room | Pending | Confirm bass slide travel and reed stability |
| VAL-008 | Bag pressure | 18-25 inH2O normal play | manometer reading | 18-25 |  | inH2O | +/-2 inH2O | player test | Pending | Log start pressure and cutoff pressure for reeds |
| VAL-009 | Bag leak | Hold pressure for 60 seconds | pressure decay test | no audible leak |  | pass/fail | No audible leak and slow pressure decay | bag assembled | Pending | Soap/bubble or manometer leak locate |
| VAL-010 | Blowpipe valve | No reverse flow | back-pressure test | no backflow |  | pass/fail | No noticeable reverse flow | bag assembled | Pending | Replace or reseat valve if failed |
| VAL-011 | Drone slide fit | Smooth travel airtight | hand force plus leak test | smooth and sealed |  | pass/fail | No binding no leak | hemped joint | Pending | Adjust hemp wrap and wax |
| VAL-012 | Stock tie-in | Five stocks airtight | pull and leak test | secure |  | pass/fail | No stock movement no leak | bag tied | Pending | Retie if movement or bubbles appear |
| VAL-013 | Maintenance 24h retest | Pitch and pressure repeatability | repeat VAL-002 to VAL-012 | within tolerance |  | mixed | +/-5 cents drift target | 24h after assembly | Pending | Identifies hemp compression and moisture drift |

## supplier-rfq.md

Supplier email/request-for-quote starter.

# Supplier RFQ - Great Highland Bagpipe Prototype

Hello,

I am sourcing parts and blanks for a first-pass Great Highland Bagpipe prototype
build. Please quote current price, availability, lead time, and shipping for the
items below. Substitutions are welcome if they preserve the stated critical
dimensions and material behavior.

## Quote Items

| Item | Required spec | Quantity | Notes |
| --- | --- | ---: | --- |
| Chanter blank | African blackwood or comparable dense stable turning blank, 2 x 2 x 16 in minimum | 1 | Straight grain, kiln dried, no checks |
| Drone blanks | Dense stable turning blanks, 2 x 2 x 10 in and 2 x 2 x 16 in | 7 | For two tenors and one bass drone |
| Stock blanks | 2 x 2 x 4 in turning blanks | 5 | Can be blackwood or Delrin |
| Delrin/acetal rod | Black acetal rod, 2 in diameter | quote lengths | Prototype alternative for chanter, drones, stocks |
| Synthetic bag | Highland bagpipe synthetic zipper bag, five stock layout | 1 | Please specify size and stock-hole layout |
| Chanter reeds | Medium Highland chanter reeds | 3 | Mixed strengths acceptable |
| Drone reeds | Synthetic set: two tenor, one bass | 1 set | Include adjustment instructions if available |
| Blowpipe valve | Flap or ball one-way valve | 1 | Compatible with Highland blowpipe |
| Waxed hemp | Yellow waxed hemp and beeswax | 1 spool | For joints and reed seats |
| Imitation ivory mounts | Delrin or bought mount/ferrule set | 1 set | Optional for prototype |

## Critical Questions

1. What are the actual dimensions and tolerances of the reed bodies/staples?
2. Does the synthetic bag ship with stock collars or tie-in instructions?
3. Are blackwood blanks waxed, kiln-dried, and suitable for long-bore turning?
4. Are substitutions available in Delrin/acetal for prototype work?
5. What is the current lead time and return policy for reeds?

Thank you.

## visual-bom-brief.md

Art direction for an image-forward visual BOM.

# Visual BOM Brief

## Goal

Create a single-page visual BOM that helps a builder see the entire bagpipe as
an interacting pressure/reed/bore system before opening the spreadsheet.

## Required Panels

1. Full system hero: bag, chanter, two tenor drones, bass drone, blowpipe, and
   five stocks labeled.
2. Chanter exploded view: reed, reed seat, conical bore, tone holes, sole.
3. Drone exploded view: reed, bottom, tuning slide, top, cap/sound exit.
4. Bag interface: stock tie-ins, blowpipe valve, pressure path.
5. Maintenance parts: hemp, beeswax, spare reeds, manometer, tuner.

## Image Requirements

- Replace the current SVG system map with shop photos once parts exist.
- Photograph each reed next to calipers before fitting.
- Photograph one hemped joint before and after wax compression.
- Include a manometer photo during the pressure validation test.
- Avoid mood-board imagery; every image should identify a physical part or
  validation step.

## Layout

- Black-on-white shop-packet version.
- Separate recruiter/site version with the same labels and a single hero image.
- Every part label must map back to `bom.csv` item IDs.

## great-highland-bagpipe-starter.wl

Wolfram starter for physics, optimization, visualization, and validation.

```wolfram
(* Great Highland Bagpipe Wolfram starter *)

ClearAll["Global`*"];

cInPerSec = 13510;
lowA = 480;

justScale = <|
  "Low G" -> 8/9,
  "Low A" -> 1,
  "B" -> 9/8,
  "C written C#" -> 5/4,
  "D" -> 4/3,
  "E" -> 3/2,
  "F written F#" -> 5/3,
  "High G" -> 7/4,
  "High A" -> 2
|>;

fChanter[lenIn_] := cInPerSec/(2 lenIn);
lChanter[f_] := cInPerSec/(2 f);
fDrone[lenIn_] := cInPerSec/(4 lenIn);
lDrone[f_] := cInPerSec/(4 f);
centsError[measured_, target_] := 1200 Log2[measured/target];

chanterTable = KeyValueMap[
  {#1, #2, N[lowA #2], N[lChanter[lowA #2]]} &,
  justScale
];

droneTargets = {
  {"Tenor A3", lowA/2, N[lDrone[lowA/2]]},
  {"Bass A2", lowA/4, N[lDrone[lowA/4]]}
};

pressureWindowInH2O = {18, 25};

Dataset[AssociationThread[
  {"Note", "Ratio", "TargetHz", "EffLengthIn"},
  #] & /@ chanterTable]

Dataset[AssociationThread[
  {"Drone", "TargetHz", "EffLengthIn"},
  #] & /@ droneTargets]

(* Suggested next cells:
   1. Import measured validation.csv rows and compute centsError.
   2. Plot chanter just-intonation targets against equal temperament.
   3. Model pressure sensitivity by fitting measured pitch vs inH2O.
   4. Use TransferFunctionModel or NDSolve for a reed-pressure toy model.
*)
```

## README.md

Project artifact.

# Great Highland Bagpipe

> A system-of-systems engineering packet for a full Great Highland Bagpipe set:
> chanter, drones, reeds, bag, stocks, blowpipe, pressure regulation, tuning,
> sourcing, maintenance, and validation.

Great Highland Bagpipe system map

## GitHub Repo Metadata

**Description:** Parametric Great Highland Bagpipe build packet covering the
chanter, tenor and bass drones, reeds, bag pressure, stocks, blowpipe, tuning,
maintenance, sourcing, and validation.

**Suggested topics:** `great-highland-bagpipe`, `bagpipe`, `woodwind`,
`reed-instrument`, `parametric-design`, `acoustic-modeling`, `cnc-lathe`,
`woodturning`, `wolfram`, `instrument-making`, `build-packet`

## What This Is

This repository turns the Great Highland Bagpipe workbook into an L2/L3-candidate
packet. It treats the instrument as an interacting set of subsystems rather
than a single pipe: the conical double-reed chanter, two tenor drones, one bass
drone, three drone reeds, one chanter reed, five stocks, blowpipe valve,
reservoir bag, hemped tuning slides, and a maintenance/validation loop.

The design starts from `great-highland-bagpipe-design-table.xlsx`, which uses a
modern GHB Low A of 480 Hz, just-intonation chanter ratios, and first-pass
dimensions for a full chanter and drone set. Formula-derived dimensions are
marked as first-order estimates until confirmed against a physical reed, bore,
and pressure setup.

## Packet Map

- [`design.md`](design.md) - governing acoustic model, subsystem interfaces,
  pressure model, assumptions, and hardware alignment.
- [`bom.csv`](bom.csv) - bill of materials with part categories, operations,
  drawing references, and substitute rules.
- [`sourcing.csv`](sourcing.csv) - supplier/search tracker with current-check
  fields left for purchasing.
- [`cut-list.csv`](cut-list.csv) - rough and finished stock sizes for chanter,
  drones, stocks, blowpipe, mounts, and fixtures.
- [`validation.csv`](validation.csv) - tuning, pressure, leakage, fit, and
  maintenance checks.
- [`assembly-manual.md`](assembly-manual.md) - shop sequence from reeds-first
  testing through final maintenance.
- [`risks.md`](risks.md) - acoustic, structural, ergonomic, supply, and
  fit/finish risk tests.
- [`drawings/`](drawings/) - first-pass dimensioned SVG sheets.
- [`cad/`](cad/) - parametric OpenSCAD master starter.
- [`site/`](site/) - static build-log site generated from the packet.

## System Architecture

| Subsystem | Function | First Prototype Decision |
| --- | --- | --- |
| Chanter | Conical double-reed melody pipe | Use the workbook's 14.5 in full-chanter length and tune holes from undersize with a commercial reed. |
| Tenor drones | Two stopped cylindrical A3 reference pipes | Build both identically; validate one tenor before copying the second. |
| Bass drone | Stopped cylindrical A2 reference pipe | Build in bottom/middle/top sections with long tuning overlap. |
| Reeds | Oscillating valves and pitch drivers | Buy commercial chanter and drone reeds for prototype stability. |
| Bag | Pressure reservoir | Buy synthetic zipper bag for repeatable airtightness. |
| Stocks and blowpipe | Airtight mechanical interfaces | Turn as separate service parts with hemped or tied-in seals. |
| Maintenance | Keeps the system stable | Add leakage, hemp, moisture, and reed checks to every validation pass. |

## Build Order

1. Buy reeds and bag first, because the acoustic system cannot be validated
   without real pressure and real reed behavior.
2. Turn a practice/prototype chanter in cherry, walnut, Delrin, or ipe before
   committing African blackwood.
3. Validate the chanter bore and note holes using tape and incremental
   enlargement.
4. Build one tenor drone, tune its reed seat and slide behavior, then duplicate
   it.
5. Build the bass drone after tenor tuning and leakage are stable.
6. Turn stocks and blowpipe, tie into the bag, and run full pressure tests.

## Status

| Area | Status |
| --- | --- |
| Workbook | Existing `great-highland-bagpipe-design-table.xlsx` inspected and promoted into packet files |
| Acoustic model | First-order conical chanter plus stopped cylindrical drones documented |
| Manufacturing plan | Lathe/CNC workflow and cut list drafted |
| Sourcing | Prototype and final-material sourcing tracker drafted |
| Validation | Tuning, pressure, leakage, fit, and maintenance checks drafted |
| Drawings | First-pass subsystem SVG drawings included |
| Site/deck/print packet | Generated artifacts live at repo root and `site/` |

## License

[CC BY 4.0](LICENSE) - see LICENSE for details.

## family-spec.csv

Project artifact.

| member_id | subsystem | target_note | target_hz | predicted_length_in | bore_in | role | prototype_priority |
| --- | --- | --- | --- | --- | --- | --- | --- |
| GHB-CHANTER | chanter | Low A | 480 | 14.5 | 0.157-0.800 conical | melody pipe | 1 |
| GHB-TENOR-1 | drone | A3 | 240 | 17.0 | 0.344/0.563 stepped | tenor drone reference | 2 |
| GHB-TENOR-2 | drone | A3 | 240 | 17.0 | 0.344/0.563 stepped | second tenor unison | 3 |
| GHB-BASS | drone | A2 | 120 | 32.0 | 0.375/0.438/0.625 stepped | bass drone reference | 4 |
| GHB-BLOWPIPE | pressure | pressure supply |  | 12.0 | 0.500 | air inlet and valve | 5 |
| GHB-STOCKS | interface | airtight fit |  | 3.0 | 0.813 nominal | bag interface set | 6 |

## photo-shotlist.md

Project artifact.

# Photo Shotlist

## Before Cutting

- Purchased chanter reeds with calipers on staple OD and blade width.
- Synthetic drone reed set with reed body diameters measured.
- Synthetic bag laid flat with stock-hole layout visible.
- Wood or Delrin blanks next to ruler and moisture/label info.

## During Build

- Chanter blank between centers before drilling.
- Bore drilling setup with tailstock and support.
- Tapered reamer entering the chanter bore.
- Tone-hole drilling fixture and front/back datum marks.
- Hemped drone slide before and after waxing.
- Stock tie-in before cover installation.

## Validation

- Manometer connected during pressure test.
- Tuner reading for Low A with pressure noted.
- Drone tuning slide position for tenor A3 and bass A2.
- Leak-test bubbles or pressure decay setup.
- 24-hour retest setup.

## Finished

- Full set assembled on bag.
- Chanter detail with reed.
- Drone tops and mounts.
- Maintenance kit: reeds, hemp, beeswax, tuner, manometer.

## risks.md

Project artifact.

# Risks - Great Highland Bagpipe

### Acoustic Chanter Bore And Reed Do Not Agree

**Symptom:** Low A speaks, but the chanter scale cannot be brought into tune by
normal tape and hole enlargement.

**Mechanism:** The conical bore, reed compliance, tone-hole network, and bag
pressure form a coupled system. A first-order `c/(2L)` estimate does not capture
the full behavior.

**Test:** Build the prototype chanter in low-cost material, record every note at
stable pressure, and compare cents error against `validation.csv`.

**Mitigation:** Keep holes undersize, test with multiple commercial reeds, and
adjust bore/hole plan before using blackwood.

**Severity:** High - human decision required before final-material chanter.

### Structural Long Bore Wanders Or Cracks

**Symptom:** Chanter or bass middle section shows off-center bore, thin wall, or
cracking during reaming/turning.

**Mechanism:** Long small-diameter bores in dense wood create heat, tool wander,
and hoop stress. Blackwood is hard and expensive but not forgiving.

**Test:** Bore and ream a prototype blank, then measure wall thickness at both
ends and inspect for heat checking.

**Mitigation:** Use headstock-supported drilling, clear chips often, prototype
in Delrin/ipe/cherry first, and reject blanks with runout or checks.

**Severity:** High - human decision required before final-material bore work.

### Ergonomic Pressure And Reach Fatigue

**Symptom:** The set can be tuned on the bench but is tiring or unstable during
real playing.

**Mechanism:** Bag size, blowpipe length, stock placement, chanter hand spacing,
and reed strength interact with player posture and arm pressure.

**Test:** Run a timed 10-minute playing simulation with manometer readings and
note any hand stretch, neck/arm fatigue, or pressure instability.

**Mitigation:** Start with a known synthetic bag size, use medium reeds, keep
the practice chanter step, and adjust blowpipe/stock ergonomics before final
decoration.

**Severity:** Medium.

### Supply Reed Or Bag Substitution Changes The Whole System

**Symptom:** A substitute reed or bag part fits mechanically but changes pitch,
pressure threshold, or stock layout.

**Mechanism:** Reed body/staple dimensions and bag stock-hole positions are not
universal across makers. The acoustic and mechanical interface can shift.

**Test:** Measure purchased reed bodies, staple OD, bag stock layout, and valve
fit before cutting reed seats or tying in stocks.

**Mitigation:** Buy coupling parts first, update drawings from measured parts,
and keep supplier substitutions out of final dimensions until measured.

**Severity:** Medium.

### Fit/Finish Decorative Mounts Lock In Before Tuning Is Stable

**Symptom:** Ferrules, imitation ivory mounts, or engraving prevent later slide,
stock, or bore corrections.

**Mechanism:** Decorative parts can hide joints, limit slide travel, or make a
prototype feel "finished" before acoustic validation is done.

**Test:** Assemble and tune the plain prototype for 24 hours before installing
permanent decorative parts.

**Mitigation:** Make mounts removable in prototype, omit engraving until the
validation report is clean, and keep slide access visible.

**Severity:** Low.

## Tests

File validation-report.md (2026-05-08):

# Validation Report - Great Highland Bagpipe

## Clean Checks

- Required Tier 1 packet files exist: design, BOM, sourcing, cut list,
  validation sheet, assembly manual, RFQ, drawing brief, visual BOM brief,
  Wolfram starter, risks, README, capstone deck, print packet, PDF, manifest,
  and generated PPTX.
- README is no longer the minimal scaffold and references an existing hero
  image at `images/ghb-system-map.svg`.
- CSV key columns are populated with explicit specs, quantities, search terms,
  dimensions, costs, or marked prototype assumptions.
- Capstone Markdown deck has 15 slides and no placeholder design-intent
  fallback.
- Printable packet artifacts generated: `print-packet.md`,
  `print-packet.html`, and `print-packet.pdf`.
- Static build-log site generated at `site/index.html`.

## Fixed In v4 Verifier Loop

- `capstone-deck.pptx` was missing because `python-pptx` is not installed in
  this environment. A minimal valid OpenXML PPTX was generated from
  `capstone-deck.md` using the Python standard library.

## Escalated

- None. `validate_packet.py . --fix` reports all gates passed.

## Remaining Prototype Work

- Supplier prices, lead times, and part dimensions must be checked before
  purchase.
- Reed-seat dimensions must be updated from the actual reeds selected for the
  prototype.
- Measured tuning, pressure, and leakage results should be recorded in
  `validation.csv` after the first physical build.

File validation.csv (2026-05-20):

check_id | subsystem | target | formula_or_spec | predicted | measured | units | tolerance | environment | result | action
VAL-001 | Reference | A4 sanity check | 440*2^((69-69)/12) | 440 |  | Hz | 0 | room | Pending | Confirms frequency formula implementation
VAL-002 | Chanter Low A | 480 Hz at stable pressure | c/(2*L_eff) | 480 |  | Hz | +/-10 cents at prototype stage | record temp humidity pressure | Pending | Set reed and pressure before hole tuning
VAL-003 | Chanter Low A effective length | c/(2*480) | 14.073 |  | in | +/-0.25 in first-order estimate | room | Pending | Compare with physical 14.5 in body and reed behavior
VAL-004 | Chanter scale all notes | Just ratios from design.md | c/(2*f_note) | see design.md |  | cents | +/-15 cents prototype; +/-5 cents final | record pressure and reed | Pending | Tune from undersize with tape/enlargement
VAL-005 | Tenor drone A3 | 240 Hz | c/(4*240) | 14.073 |  | in effective | +/-0.5 in before slide tuning | room | Pending | Check slide range before duplicate tenor
VAL-006 | Tenor drone frequency | 240 Hz with chosen reed | stopped pipe plus reed/slide | 240 |  | Hz | +/-5 cents against chanter Low A | record pressure and reed | Pending | Adjust reed bridle/screw then slide
VAL-007 | Bass drone A2 | 120 Hz | c/(4*120) | 28.146 |  | in effective | +/-1.0 in before slide tuning | room | Pending | Confirm bass slide travel and reed stability
VAL-008 | Bag pressure | 18-25 inH2O planned normal-play window | manometer reading | 18-25 planned |  | inH2O | measurement_required | player test | Pending | Log measured start normal-play and cutoff pressure before treating the range as evidence
VAL-009 | Bag leak | Hold pressure for 60 seconds | pressure decay test | no audible leak |  | pass/fail | No audible leak and slow pressure decay | bag assembled | Pending | Soap/bubble or manometer leak locate
VAL-010 | Blowpipe valve | No reverse flow | back-pressure test | no backflow |  | pass/fail | No noticeable reverse flow | bag assembled | Pending | Replace or reseat valve if failed
VAL-011 | Drone slide fit | Smooth travel airtight | hand force plus leak test | smooth and sealed |  | pass/fail | No binding no leak | hemped joint | Pending | Adjust hemp wrap and wax
VAL-012 | Stock tie-in | Five stocks airtight | pull and leak test | secure |  | pass/fail | No stock movement no leak | bag tied | Pending | Retie if movement or bubbles appear
VAL-013 | Maintenance 24h retest | Pitch and pressure repeatability | repeat VAL-002 to VAL-012 | within tolerance |  | mixed | +/-5 cents drift target | 24h after assembly | Pending | Identifies hemp compression and moisture drift
VAL-014 | Chanter reed onset | Low A starts before normal play pressure | reed-pressure-validation.csv RP-002 | TBD |  | inH2O | measurement_required | manometer plus tuner | Pending | Measure reed onset before opening tone holes further
VAL-015 | Chanter pressure response | Low A and sample scale notes stay stable at 18/21/25 inH2O | reed-pressure-validation.csv RP-003 | TBD |  | Hz/cents | measurement_required | record reed temp humidity pressure | Pending | Separate reed strength problems from hole-position problems
VAL-016 | Chanter cutoff margin | Cutoff or warble threshold stays above normal play pressure | reed-pressure-validation.csv RP-004 | TBD |  | inH2O | measurement_required | controlled overpressure test | Pending | Do not tune permanent holes until cutoff margin is known
VAL-017 | Tenor drone reed onset/restart | Reference tenor starts and restarts predictably | reed-pressure-validation.csv RP-005 | TBD |  | inH2O | measurement_required | manometer plus tuner | Pending | Validate first tenor before duplicating second tenor
VAL-018 | Tenor drone pressure response | A3 remains stable at 18/21/25 inH2O | reed-pressure-validation.csv RP-006 | TBD |  | Hz/cents | measurement_required | record reed and slide setting | Pending | Adjust reed before slide or bore changes
VAL-019 | Bass drone reed onset/cutoff | Bass starts and stays stable through normal play pressure | reed-pressure-validation.csv RP-007 | TBD |  | inH2O and Hz | measurement_required | manometer plus tuner | Pending | Keep bass slide and bore claims provisional until measured
VAL-020 | Full set coupled response | Chanter plus drones remain stable at shared pressure targets | reed-pressure-validation.csv RP-008 | TBD |  | mixed | measurement_required | drones-alone then full-set comparison | Pending | Do not promote coupled tuning claims without this evidence
VAL-021 | Pressure system control | Bag stocks and valve pass pressure hold before reed interpretation | reed-pressure-validation.csv RP-009 | TBD |  | inH2O decay | measurement_required | 60-second pressure decay test | Pending | Fix leaks before interpreting reed data

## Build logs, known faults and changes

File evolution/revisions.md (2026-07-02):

# Revision Register — great-highland-bagpipe

| Rev | Date | Parent | Delta | Downstream artifacts invalidated |
| --- | --- | --- | --- | --- |
| A | 2026-07-01 | — | Stage 0 intake of current masters (cad/great-highland-bagpipe-master.scad + great-highland-bagpipe-design-table.xlsx + newly generated wolfram/great-highland-bagpipe-wolfram-model.wl). | none (no alpha/beta/production artifacts exist yet) |

Stage 0 only. Gate A has not been run; no Alpha compiles, vendor quotes, or production lock exist for this product.

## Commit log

2026-05-02 Initial scaffold: Great Highland Bagpipe
    [great-highland-bagpipe-design-table.xlsx]
2026-05-20 Add GHB reed pressure validation gates (#5)
    * Add GHB reed pressure validation gates
    * Mark GHB pressure window as measurement required
    ---------
    [family-spec.csv, reed-pressure-validation.csv, validation.csv]
2026-05-30 Add V5 visual register, mcp log, and L2 status (Refs #1) (#6)
    Adds visual-output-register.csv registering SVG drawings (derived_preview),
    system map (concept_only), OpenSCAD SCAD (pending_measurement), and
    print-packet.pdf (derived_preview).
    Adds cad/mcp-session-log.md for V5 provenance on SCAD and SVG outputs.
    Updates README to Status: L2 V5 build-packet candidate.
    All validation gates remain Pending.
    [visual-output-register.csv]
2026-05-31 Add image-gen concept prompt; wire explorer images
2026-06-21 Wire 3 rendered concept image(s) into explorer gallery
2026-07-02 V5 packet refresh: status line fix, Wolfram model, provenance, evolution intake
    Validator: python3 validate_v5_packet.py . --slug great-highland-bagpipe -> 1 failure -> 0 failures, 1 pre-existing warning unchanged (master-scad authority WARN). Fixed README status-line format (bold-colon bug: "**Status: L2...**" -> "**Status:** L2..."), no level change (stays L2 candidate). Generated wolfram/great-highland-bagpipe-wolfram-model.wl via generate_wolfram_packet.py (not executed), added register + provenance rows. Existing cad/great-highland-bagpipe-master.scad kept as-is, render-checked (openscad -o STL, exit 0). Added evolution/ Stage 0 intake.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
    [visual-output-register.csv]
